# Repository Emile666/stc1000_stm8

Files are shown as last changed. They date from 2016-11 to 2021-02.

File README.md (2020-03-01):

STC-1000p-STM8
==========

This version of the STC-1000p (STC-1000p-STM8) is heavily based on the beautiful work from Mats Staffansson (https://github.com/matsstaff/stc1000p), where he creates an open-source implementation of firmware(s) for the STC-1000 dual stage thermostat.
Mats version is used by numerous home-brewers for automating their brewery / climate chamber. The hardware is controlled by a **PIC16F1828** microcontroller (µC), which is pretty limited. Despite these limitations Mats succeeded in
adding 6 profiles with up to 9 temperature-time pairs per profile.

I bought a couple of STC-1000 devices which had another µC with completely different hardware on-board. It is the **STM8S003F3** µC. Being the electrical engineer that I am, I wanted to reverse engineer
the hardware, create the schematics and new boards and (like Mats) add new features. You can find the schematics (with the Eagle design files) all here. I also used Mats software as a start, but needed to heavily modify it in order
to run on the new hardware platform.

The following additional features were added, which were not present in Mats' firmware (See the [user-manual](./usermanual/README.md) for more details):
- **PID-Control with SSR**: This firmware version has PID-control built-in and the output is available at the connector block for direct control of a Solid-State Relay (SSR). Just set the **Ts** parameter to a non-zero value to enable PID-control.
- **Refrigerator mode with compressor fan control**: If you connect a second temperature probe and set the **Pb2** parameter to 2, you can control a refrigerator and the compressor fan at the same time. The first temperature probe goes inside the refrigerator as usual, the second one is connected to one of the compressor output pipes. The cooling output controls the refrigerator itself, the heating output is now used for the compressor fan. I am using this to control a keg-cooler (replacing the stock controller for a STC1000).

So, for those of you who have this version of the STC-1000: enjoy! Because now you can have the same (and more) functionality as Mats realised in the PIC version of the STC-1000. There's only one real drawback: the STM8 µC
only has 128 bytes of EEPROM, so the number of profiles and the number of temperature-time pairs per profile needed to be reduced. But you get more features as a standard (switchable) option (instead of programming a different firmware version). 
For those of you willing to do some de-soldering (see text below): you can replace the µC with a **STM8S103F3** µC that has 640 bytes of EEPROM. Then you have the 6 profiles with all temperature-time pairs again.

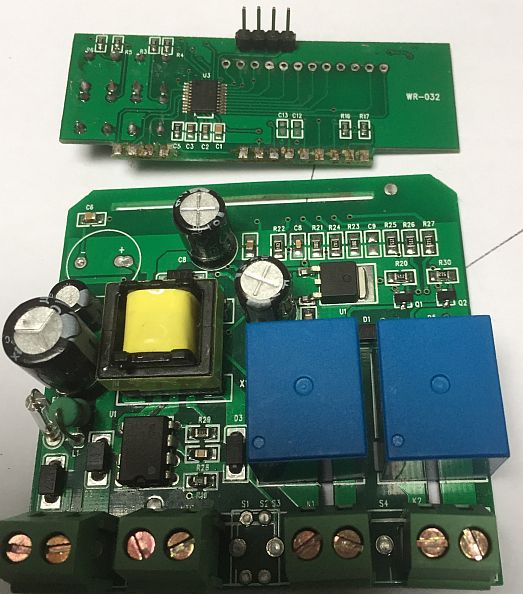
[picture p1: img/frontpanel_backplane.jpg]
STC-1000
<br>
*The frontpanel and backplane of the STC-1000 device*

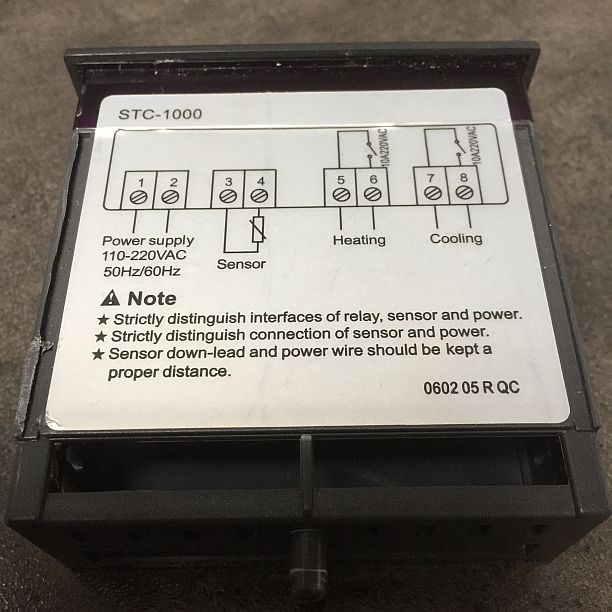
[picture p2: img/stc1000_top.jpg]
stc-1000-top
<br>
*The top of the STC-1000 device. Note the label '0602 05 R QC'*

If you happen to have an STC-1000 device without the label, you could have the newer hardware revision (**WR-032 v2**). It is almost the same, but has a few changes. Read more about this [here](./WR-032-v2-2016-4-7.md).

Questions?
----------
Please don't open github issues for general questions. Only open an issue if you discovered an actual bug or have a (realistic) feature request (or better yet, send a pull request).

Quick start
-----------
You'd need one of those fancy coloured ST-Link V2 USB adapter (which are very cheap to find on ebay) and of-course an STC-1000 with a STM8. Mine has a label '0602 05 R QC' on top, the Printed Circuit-Board (PCB) itself has a mark 'WR-032'.
 
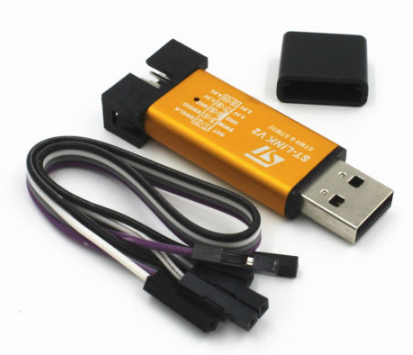
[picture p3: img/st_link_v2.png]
st-link-v2
<br>
*The ST-Link V2 USB adapter*

The frontpanel PCB already has a 4-pin connector (labeled with SIG, RST, VCC and GND). Solder some pins to this and connect the ST-Link adapter (use GND-GND, RST-RST and SWIM-SIG). Power up the STC-1000 device, so that it uses it's own
power-supply (in this way, the 4th VCC pin on the connecter is not needed). **Please be aware that most of the PCB is directly connected to the MAINS voltage, so keep your fingers out of it!**

This is all you need to reprogram the device! Now power-up the STC-1000 and connect the ST-Link V2 USB to it. 

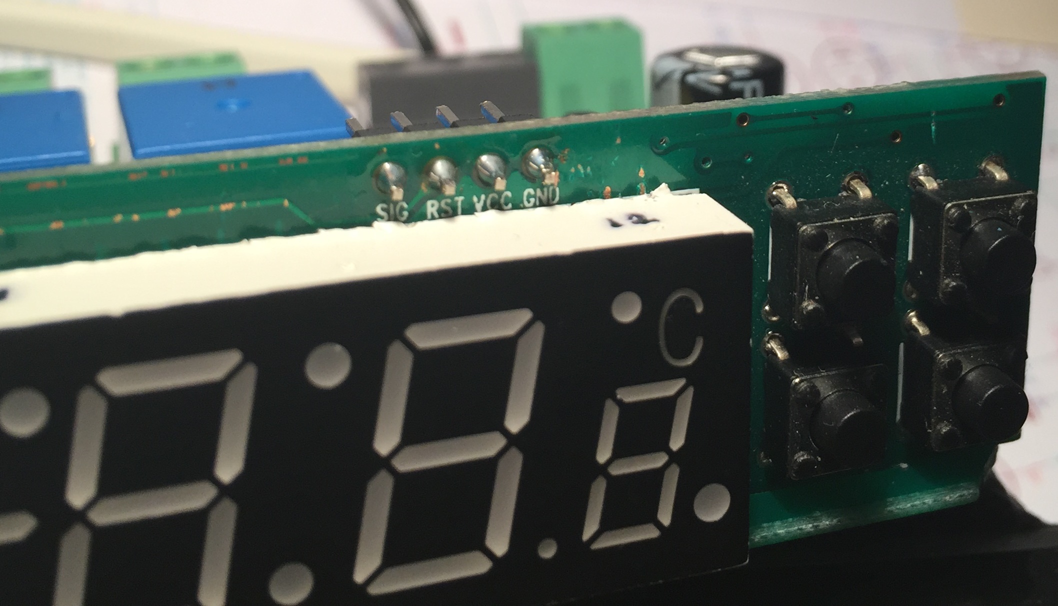
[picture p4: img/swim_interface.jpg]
swim-interface
<br>
*The Programming Interface. Note that you have to solder the 4-pins in place!*

Method 1: Just program it with ST Visual Programmer
-------------------------
This is the best method if you just want to flash the STC-1000 with the software provided and you don't want to change any software functionality.

- Download the ST Visual Programmer (STVP) software, unpack the .zip file and install it. This file can be downloaded free of charge from the ST website (st.com). Just search for 'STVP-STM8', the file to download is called en.stvp-stm8.zip.
- Run the STVP program, then click on Project -> Open..., select the **stvp_stm8s003f3_4pr_5tt.stp** file and open it. This file is located in src\Debug\Exe. You can safely ignore the 'address out of range' warnings, this is not a problem. Both the *Program Memory* tab and the *Data Memory* tabs are now filled with the data from the .hex file. Check that these tabs are indeed filled with data.
- Now find the button that says "Program all tabs" or click Program->All Tabs. This will program the microcontroller with the new functionality.

Note: there's also a project and .hex file for the **STM8S103F3** microcontroller (with 6 profiles and 9 temperature-time pairs). Use this version when you have replaced the stock microcontroller (see text below).

Method 2: Program and install complete development environment
-------------------------
This is the best method for anyone wanting to flash the STC-1000 and be able to make changes to the software.

- Download and install the IAR development environment for STM8 from the IAR website, which can be downloaded free of charge. Use the code-size limited version. After having installed this, the drivers for the ST-Link USB adapter are also installed.
- If you have downloaded the project- and source-files, open the workspace in IAR (File -> Open -> Workspace... -> stc1000p_dev.eww), then do a Project -> Rebuild All.
- The µC has Read-Only-Protection (ROP) enabled and this needs to be disabled before the new firmware can be uploaded. Click on ST-LINK -> Option Bytes... The following dialog box opens:
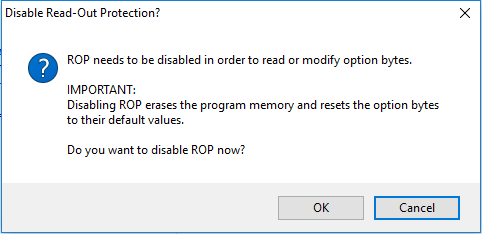
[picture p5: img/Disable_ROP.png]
rop-protection
<br>
*The Read-Only-Protection dialog box. Press OK to continue*
- If ROP protection is disabled (and your stock program has been erased, with no way of getting this back), press Ctrl-D. This opens the debugger and transfers the code to the microcontroller. 
- Press Ctrl-Shift-D to Stop Debugging. Remove the wires, re-cycle power and you are good to go!

Introduction (taken from https://github.com/matsstaff/stc1000p)
----------------------------------------------------------
The STC-1000 is a dual stage (that is, it can control heating *and* cooling) thermostat that is pretty affordable. It is microcontroller operated, that means there is a sort of 'computer on a chip' that reads the temperature of the probe, turns the relays on and off, reads the state of the buttons and updates the display. 
To do all this, the microcontroller needs to be programmed to perform these tasks. The program is stored in non volatile (flash) memory that is retained when there is no power. The microcontroller can be reprogrammed (flashed) with a new program (firmware), that can other or additional tasks. 
To do that, a new firmware is needed and you need a programmer that can send it to the microcontroller the way it expects it. The STC-1000\-STM8 project provides both these things (and a few additional things as well).

So far so good, *but* there is a catch. Probably due to the popularity of the STC-1000, there are a number of clones out there. These are functionally (from a user perspective) equivalent, but are not based on the same design. 
Specifically, they use other microcontrollers that while having similar specifications, use completely different architectures. 

This STC-1000+ version is *only* compatible with the **WR-032** version of the STC-1000 as this supports the **STM8S003F3** microcontroller, for which you have a code-size limited (8K) version of IAR available. IAR is the embedded development tool which you use to program the device in the C-language.
To upload (flash) the microcontroller, you also need the ST-Link V2 USB adapter ($2-$3 on ebay). There are official ST-Link programmers to purchase, but they typically cost a lot more. Neither of these options are very cost effective, considering the price of the STC-1000. 

Schematics
----------
I reversed engineered both the frontpanel PCB as well as the backplane PCB. The frontpanel PCB holds the buttons, the 7-segment display (3 digit common-cathode) as well as the **STM8S003F3** µC. There's an ingenious soldered connection that connects the frontpanel PCB to the backplane PCB. The backplane PCB holds both relays (able to switch 12A at 230VAC), the power-supply (12V and 5V) and the connectors. The schematics were made with the Eagle PCB program.

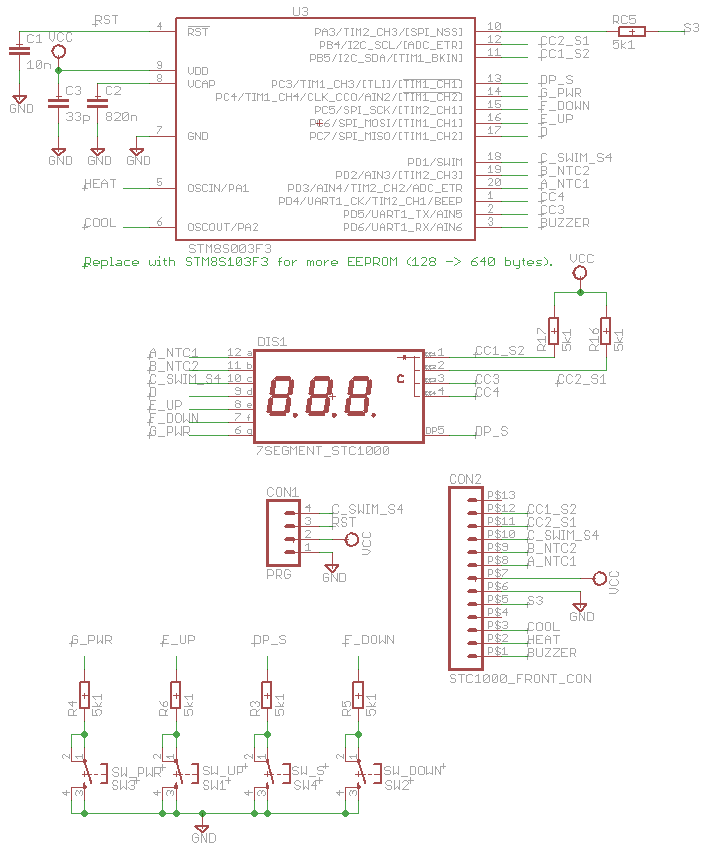
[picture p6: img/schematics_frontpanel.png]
frontpanel
<br>
*Eagle schematic of the Frontpanel PCB*

Two interesting features are shown in this schematic:
- The **S1** and **S2** lines. It looks likes this is an **I<sup>2</sup>C** interface. Interesting feature for those of you willing to do some more hacking! It is not used in this firmware version, these lines are solely for multiplexing the 7-segment displays.
- The **S3** line. Now this is interesting, it is the only hardware pin *NOT* used. The new firmware uses it to switch an SSR (with a slow PWM signal) controlled by a PID-controller. But I guess it can be used for other purposes as well.

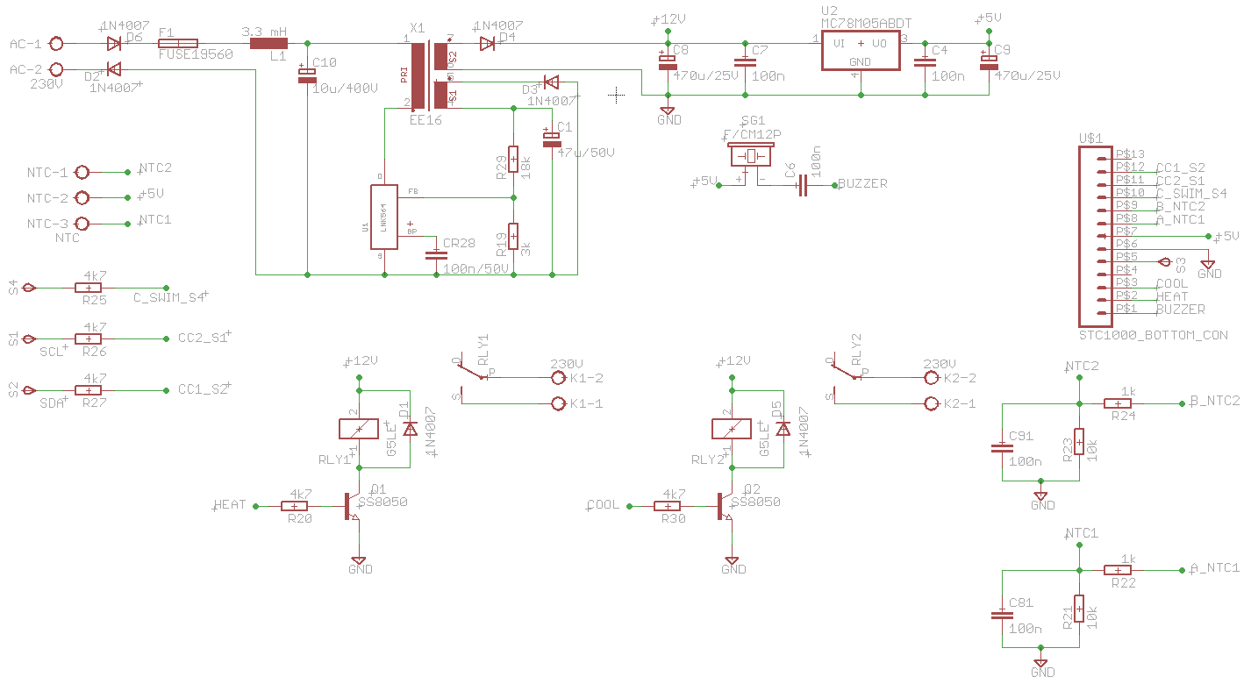
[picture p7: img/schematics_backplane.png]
backplane
<br>
*Eagle schematic of the Backplane PCB*

Replacing the STM8S003F3 µC for more EEPOM size
-----------------------------------------------
You do not need to do this, but if you replace the existing **STM8S003F3** microcontroller (µC) with a **STM8S103F3** µC, you get 640 bytes of EEPROM and you can have 6 profiles with up to 9 temperature-time pairs (same as in Mats his version).
You can skip this section if you are not into soldering small devices and the default profiles are oke for you. To replace the device, you would need the following:
- A new **STM8S103F3P6** device (Mouser part nr. 511-STM8S103F3P6). This is a 20-pin TSSOP package that costs about a $1.
- A hot-air rework station for SMD devices (I bought a 858D hot-air station that is very affordable on ebay)
- A soldering iron.
- Solder wick.
- Solder paste. This typically comes with an injection-needle for applying just a little paste on every solder pad.

To start with, we want to remove the frontpanel PCB from the backplane. Remove all the solder-joints with the solder wick. Place the solder wick over the solder-joints, heat it up with the soldering iron and make sure that the solder wick absorbs all solder.
After having done this, it is possible to remove the frontpanel from the backplane with just a little bit of pulling. Be careful, since you don't want to break anything.

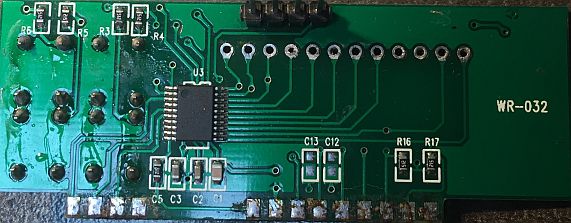
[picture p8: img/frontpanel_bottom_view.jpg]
frontpanel removed
<br>
*This is how it looks after the frontpanel is removed from the backplane*

Next: use the hot-air to heat-up the pins on one side of the µC. Use a sharp knife and place it under the µC. Carefully lift-up one side. Do not overheat, since you could damage the PCB tracks. If this is done, let it cool down and heat-up the other side. When the solder melts, it is easy to remove the µC. Use the solder-wick again to remove excess solder from the solder-pads.

If you don't have access to a hot-air rework station, here's a tip from Mats himself: one can can simply thread a thin wire under the legs on one side of the IC, fix one end of the wire and heat the legs with a soldering iron (starting at the other end) while keeping the wire under tension. As the solder melts, you pull the wire under the leg/pad, freeing them.

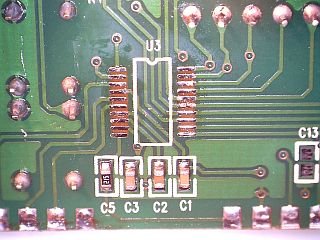
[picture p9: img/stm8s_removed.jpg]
uC removed
<br>
*This is how it looks after the microcontroller is removed*

Then: apply solder paste to the solder-pads of the µC and position the **STM8S103F3P6** µC exactly above the pads. Note the orientation of the device (there's a small circle denoting pin 1), you don't want to solder it upside-down! Position the µC exactly above the solder-pads, make sure the position is correct for all pins and use the hot-air station again to solder the new IC. Let is cool down again. It would be wise at this point to connect the ST-Link V2 USB device to the programming connector and see if you can connect to the device. If all is well, solder both PCB boards back together. If not, check all solder-joints to see if one or more pins are not connected properly.

Updates
-------

|Date|Release|Description|
|----|---|---|
|2016-12-02|v1.10|reduced code-size by removing unions and bit-fields. Added description how to flash firmware with STVP program. Description added for v2 hardware.|
|2016-10-27|v1.00|First release, copied from https://github.com/matsstaff/stc1000p |

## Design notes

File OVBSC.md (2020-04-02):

STC\-1000+ One vessel brew system controller, STM8 version
============================================
This is a firmware version for the STC-1000 dual stage thermostat with an STM8 microcontroller. The purpose is to serve as a simple semi-automatic controller for a one vessel brewing system (OVBSC).
Note: almost all information on this page is a direct copy from Mats' OVBSC page (https://github.com/matsstaff/stc1000p/tree/master/ovbsc). There are however a few modifications made in this firmware, the most important one
being that there are no constant output (cO) parameters anymore. This is replaced by a PID-controller that controls the output.

By using a separate output for a Solid-State-Relay (SSR), you can connect any type of heater, since an SSR can typically switch a large current.

Features
--------
* Fahrenheit and Celsius adjustable
* Cheap, simple, semi automated one vessel brewing control
* Controls a pump and an electric heater
* Separate heater output for PID-controlled Solid-State-Relay (SSR)
* Alarm when user interaction is required
* Possible to delay heating of strike water
* PID-control during entire brew for accurate temperature control
* Four run-modes: OFF, run-program, constant output and constant temperature
* TODO: Manual pump control (on/off toggle) by pressing Up key for 3 seconds
* TODO: Heater control (on/off toggle) by pressing Down key for 3 seconds
* 1-6 mash steps, 0-4 hop addition alarms
* Pause program at any time
* Button acceleration, for frustrationless programming by buttons

Parameters
----------
|Menu item|Description|Values|
|---|---|---|
|Sd|Strike delay|0-999 minutes|
|St|Strike water setpoint|-40.0 to 140°C or -40.0 to 250°F|
|Pt1|Mash step 1 setpoint|-40.0 to 140°C or -40.0 to 250°F|
|Pd1|Mash step 1 duration|0-999 minutes|
|Pt2|Mash step 2 setpoint|-40.0 to 140°C or -40.0 to 250°F|
|Pd2|Mash step 2 duration|0-999 minutes|
|Pt3|Mash step 3 setpoint|-40.0 to 140°C or -40.0 to 250°F|
|Pd3|Mash step 3 duration|0-999 minutes|
|Pt4|Mash step 4 setpoint|-40.0 to 140°C or -40.0 to 250°F|
|Pd4|Mash step 4 duration|0-999 minutes|
|Pt5|Mash step 4 setpoint|-40.0 to 140°C or -40.0 to 250°F|
|Pd5|Mash step 4 duration|0-999 minutes|
|Pt6|Mash step 4 setpoint|-40.0 to 140°C or -40.0 to 250°F|
|Pd6|Mash step 4 duration|0-999 minutes|
|Ht|Hot break temperature|-40.0 to 140°C or -40.0 to 250°F|
|Hd|Hot break duration|0-999 minutes|
|bt|Boil temperature|-40.0 to 140°C or -40.0 to 250°F|
|bd|Boil duration|0-999 minutes|
|hd1|Hop alarm 1|0-999 minutes|
|hd2|Hop alarm 2|0-999 minutes|
|hd3|Hop alarm 3|0-999 minutes|
|hd4|Hop alarm 4|0-999 minutes|
|cF|Celsius or Fahrenheit display|0 = Celsius, 1 = Fahrenheit|
|tc|Temperature correction|-5.0 to 5°C or -10.0 to 10.0°F|
|Hc|Kc parameter for PID-controller in %/°C|-9999 to 9999|
|Ti|Ti parameter for PID-controller in seconds|0 to 9999|
|Td|Td parameter for PID-controller in seconds|0 to 9999|
|Ts|Ts parameter for PID-controller in seconds|0 to 9999|
|APF|Alarm/Pause control flags|0 to 511|
|PF|Pump control flags|0 to 31|
|cO|Manual mode output when Run mode is OFF|-200 to 200%|
|cSP|Manual mode temperature setpoint when Run mode is OFF|-40.0 to 140°C or -40.0 to 250°F|
|cP|Manual mode pump when Run mode is OFF|0 (=off) or 1 (=on)|
|ASd|Safety shutdown timer|0-999 minutes|
|rUn|Run mode|OFF, Pr (run program), Ct (manual mode thermostat), Co (manual mode constant output)|

Note on APF parameter: APF is a parameter that holds flags to enable/disable the alarm/pause points during the program. By default all alarms/pause points are enabled, but this parameter allows the user to skip some/all of them if so desired. To make adjustments, the desired behaviour needs to be calculated.

|Value|Description|
|---|---|
|1|Strike temp reached/dough in alarm|
|2|Strike temp reached/dough in pause|
|4|Mash done/sparge/start boil up alarm|
|8|Mash done/sparge/start boil up pause|
|16|Hop addition 1 alarm|
|32|Hop addition 2 alarm|
|64|Hop addition 3 alarm|
|128|Hop addition 4 alarm|
|256|Boil done/start chill alarm|

Add up the values for the alarms/pause points desired, and set that value to the APF parameter. Say for example you'd like to mash in cold, and want the controller to skip the alarm and pause after strike temp is reached, and just continue with the mash profile (but still keep the other alarms/pause points). Then sum up all the alarms (511) and subtract 1 (strike temp reached alarm) and 2 (strike temp reached pause). The value (508) is what you'd want to enter in APF.

Note on PF parameter: The PF parameter holds flags to indicate pump status during different stages of the program. By default the pump is on during the mash.

|Value|Description|
|---|---|
|1|Pump during heating of strike water|
|2|Pump during ramping up to reach next mash steps|
|4|Pump during the mash steps|
|8|Pump during heating up to reach hot break|
|16|Pump during hot break|

Similar to the APF parameter. Add upp the values of the stages when the pump should be active and enter it into the PF parameter.

Hardware usage
--------------

Pretty simple really. The cool output relay is used to control a pump, the S3 output is used to connect a Solid-State-Relay (SSR) that connects to a heater. See the 'PID-output for connection to a Solid-State Relay (SSR)' 
section in the [user-manual](./usermanual/README.md) for details.

The output is specified as a percentage and is controlled with slow PWM (that is they are pulsed on/off). So for example, if the PID-output is 75%, the SSR switches 9.375 seconds ON and 2.625 seconds OFF (timebase for this slow PWM signal is 12 seconds).
Typically there's a LED on a SSR, so you can see when the SSR is on or off. Also, the heating LED on the display shows the SSR status. The PID-controller is active most of the time and only needs a setpoint temperature to control everything. 
This is also the case in 'constant temperature' mode where it uses the *cSP* setpoint temperature. Only in 'constant output' mode, the PID-controller is not used and the controller output is directly set to *cO* percent.

Program algorithm
-----------------

* Wait *Sd* minutes (with all outputs off)
* PID-controller on with setpoint *St*
* Wait until temp >= *St* (or end program if countdown-timer = 0)
* St alarm if APF flag set, countdown-timer = *ASd* minutes
* Wait until keypress (or end program if countdown-timer = 0)
* Pause if APF flag set (output off, pump off)
* (This is when you dough in and do manual vorlauf)
* Wait until power key is pressed
* *x* = 1
* *Init mashstep*: PID-controller uses setpoint *Ptx*, pump on if PF flag set, countdown = *ASd* minutes
* Wait until temp >= *Ptx* (or end program if countdown-timer = 0)
* countdown-timer = *Pdx*, pump on if PF flag set
* Wait until countdown-timer = 0
* x = x+1
* if x <= 6 goto *Init mashstep* 
* bU alarm if APF flag set, countdown-timer = *ASd* minutes
* Wait until keypress (or end program if countdown-timer = 0)
* Pause if APF flag set (output off, pump off)
* (This is when you remove grains and sparge)
* Wait until power key is pressed
* PID-controller uses setpoint *Ht*, pump on if PF flag set, countdown-timer = *ASd* minutes
* Wait until temp >= *Ht* (or end program if countdown-timer = 0)
* countdown-timer = *Hd* minutes, pump on if PF flag set
* Wait until countdown-timer = 0
* PID-controller uses setpoint *bt*, countdown-timer = *bd* minutes, pump off
* Wait until countdown-timer = 0, if countdown-timer = *hdx* then hdx alarm if APF flag set
* Ch alarm if APF flag set, output = 0, pump off, end program

During the program the keys have the following function:
- a single press on the power button will pause the program (during pause, a LED will flash and all outputs will be off). Press the power button again and the program will resume.
- a 3-second press on the Up key toggles the pump on/off (not implemented yet).
- a 3-second press on the Down key toggles the PID-controller on/off (not implemented yet).

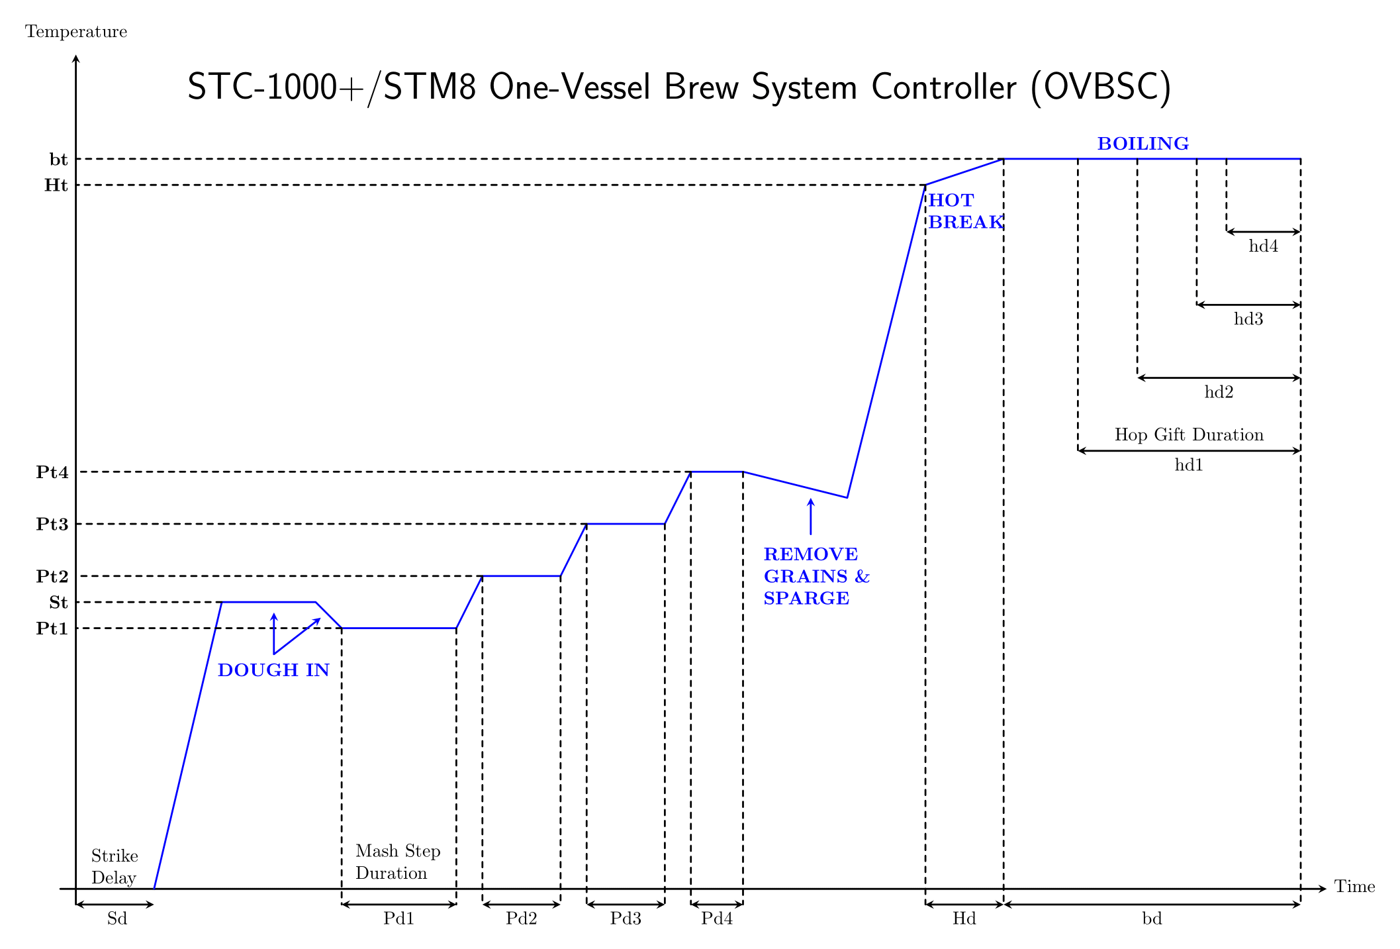
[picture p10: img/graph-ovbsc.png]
Graphical representation
<br>
*Fig4: Graphical representation of the algorithm*

Now, I will try as best I can, to explain the algorithm and key concepts in 'english'.<br>
The program starts off with a delay of *Sd* minutes (strike delay), during this time it will do nothing but wait. This can be useful if you want to delay the heating of strike water, so it will be warm by the time you need it 
(don't recommend leaving it unattended, do so at your own risk). *Sd* can of course be set to 0 to start immediately.<br>

Reaching strike temperature is done by the PID-controller that uses setpoint value *St*. If the PID-controller is properly tuned (*Hc*, *Ti*, *Td*, *Ts* parameters), it will quickly reach its setpoint-temperature with no overshoot.<br>

Once strike temperature is reached, the alarm will go off if the corresponding APF flag is set and 'St' will flash on the display. The PID-controller will continue to control the *St* setpoint temperature. 
If the alarm is not acknowledged within *ASd* (automatic shutdown delay) minutes, the program will be stopped. Once acknowledged (by pressing any button), the program will pause if the corresponding APF flag is set 
(all outputs off) and during this pause you dough in your grains. Press the *power* button to continue the program.<br>

In a similar way, for each of the mashing steps, the PID-controller will continue to control the temperature by using the proper setpoint-temperature (*Pt1* to *Pt6*). Once this setpoint-temperature is reached, it holds the mash
step temperature for the programmed duration.<br>

When mashing is done, the alarm will go off again (again if the corresponding APF flag is set) and 'bU' (boil up) is flashing on the display. The PID-controller will now use the *Ht* setpoint temperature. Acknowledge the alarm and the unit will pause (APF flag...) again. Remove the grains and optionally sparge manually. Press *power* button to resume. <br>

Once *Ht* (hotbreak temperature) is reached, the PID-controller holds this temperature for *Hd* (hotbreak duration) minutes. The purpose of this, is that as the wort reaches boiling temp, proteins clump together and a foam is formed on the surface. The added nucleation points as well as the insulating effect of the foam can easily contribute to boil over. The heat will shortly break down the proteins (hot break), that will settle to the bottom of the kettle. So, to avoid boil over the power is reduced during this period. As an educated guess, you might want to set *Ht* a degree or so shy of your normal boiling temperature and *Hd* should probably be around 15 minutes.<br>

When *Hd* has passed, normal boil starts and the PID-controller now uses the *bt* setpoint temperature. Setting this temperature to 102-105 °C assures that the PID-output is 100 % on all the time. The timer also starts counting down the boil duration *bd*. When the timer matches a hop addition the alarm will sound and *hdx* will flash on the display. Acknowledge the alarm by pressing any button (and add the hops of course). Note that the *hdx* settings are in standard hop addition times as used in most recipies, that is the boil duration counted back from boil end.<br>

Once the boil is complete, output is turned off and the alarm goes off (flashing 'Ch' for chill). Acknowledge and chill your wort.<p>

An important note on *ASd*. This is in my opinion an important feature. Many of the steps in the program are timed. For example mash durations, boil duration and so on. But not every step is, for example, when 'stepping up' the temperature, the program will continue to heat until the temperature is reached, or during an alarm (except hop additions, during which the boil duration timer is running) when user input is required, during these times the timer is loaded with *ASd* instead and if not the condition is met within this timeframe, the program stops. This is of course for safety. *ASd* should therefore be set to the maximum of these duration + some wiggle room. For example, if it takes you around 35 minutes to reach strike temp and this is the longest of these delays, maybe set *ASd* to 45 minutes.<br>

Also, a note on switching times. The SSR is controlled with a fixed switching period (12.5 seconds). This is slow enough to control any large heating element (I connected a 3 kW heating element without any problem at all).

Updates
-------

|Date|Release|Description|
|----|---|---|
|2020-04-01|v1.00|First release, copied from Matsstaf and modified|

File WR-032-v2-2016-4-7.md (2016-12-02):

# New hardware revision WR-032 v2
==========

Recently (november 2016) I bought a couple of new STC-1000 devices and was amazed that, instead of the familiar WR-032 label, a new hardware revision was shipped. It was labeled **WR-032 v2** with date **2016/4/7**.

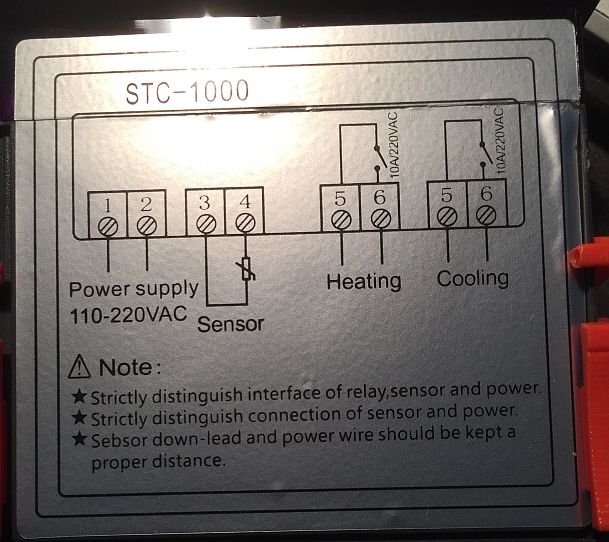
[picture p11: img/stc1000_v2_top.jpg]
stc-1000-top
<br>
*The top of the new STC-1000 device. Note that there's no label anymore!*

The frontpanel does state **WR-032 v2** but it seems that this is still the same as the original version. The microcontroller is still the **STM8S003F3** device, so no changes here. Only the backplane shows some changes.

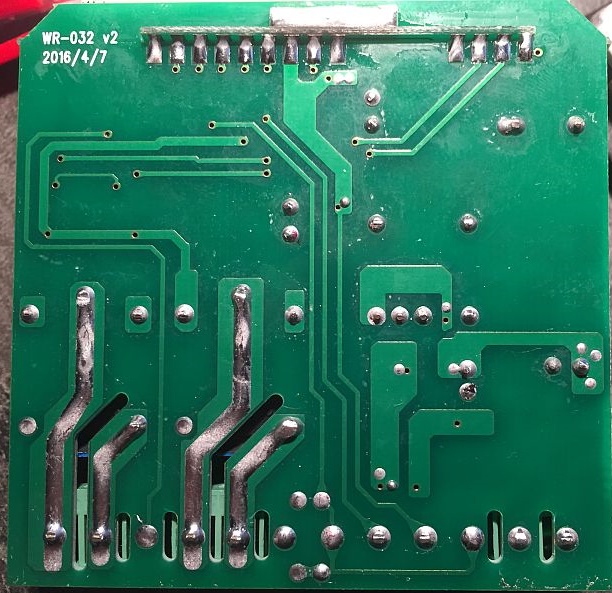
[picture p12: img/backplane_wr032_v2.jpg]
<br>
*The backplane of the STC-1000 device with the new hardware revision*

## What has changed from the first WR-032 revision?
----------
To start with, the new hardware revision is definitely NOT an improvement. No new features are added. The following things have changed:
- The DC-DC converter chip (LNK567) has been replaced by another IC. This is not something to worry about: there's still 12VDC and 5VDC being made
- The **S3 output** line is no longer wired to the terminal-blocks.
- The 2nd temperature probe is now also wired to the terminal-block pin (pin 4) that we used as GND. This needs to be fixed if we still want PID-controlled SSR output.
- Capacitor C9 is now populated (temperature conversion for 2nd temperature probe). This has no impact on the STC-1000p-STM8 firmware, since the ADC-input routine already deals with this.
- Resistors R25 (S4 output), R26 (S1 output) and R27 (S2 output) are no longer populated. This is also not a problem.

## What do we need to change?
-----------
- The GND connection at the 5-pin terminal-block needs to be connected to GND again. It is now connected to the second temperature probe.
- The **S3 output** needs to be connected to the SSR connection at the 5-pin terminal-block. This pin is now NOT connected.

## What if I don't want to change anything?
----------------------------------------------------------
- You loose the slow-PWM PID-controlled SSR output.
- A 5-pin terminal-block is no longer useful, since pin 4 is now connected to pin 1 (2nd temperature probe) and pin 5 is not connected. Solder a 3-pin terminal block in place, so you can still connect a 2nd temperature probe.

All other functionality will remain intact. So you can still have 2 temperature probes. Up to you to decide if you need to make the hardware changes.

## Ok, what do I need to change?
----------
To get the same functionality as with the original WR-032 hardware (in combination with the STC-1000p-STM8 firmware of-course), you need to prepare the connectors the same way you did with the original version:
- Remove the 2-pin terminal-block for the temperature sensor.
- Replace it with a 5-pin terminal-block with a pitch of 5 mm.

Then, proceed with the following:
- Cut the 2 wires going to and from pin-4 of the 5-pin terminal block. Cut where the **red** lines are in the picture. This pin is now completely isolated from anything else. Measure with a multimeter!
- Solder a wire between pin 1 of the 5-pin terminal block to the S1 solder-pad. This is the **yellow** line in the picture. Now the 2nd temperature probe is connected again with the original line.
- Solder the now isolated pin-4 of the 5-pin terminal block to the GND connection of the 470 µF/25V capacitor. This is the **black** line in the picture.
- Solder pin 5 of the 5-pin terminal-block to pin 5 of the frontpanel connector. This is the **S3-output** line and the **blue** line in the picture.

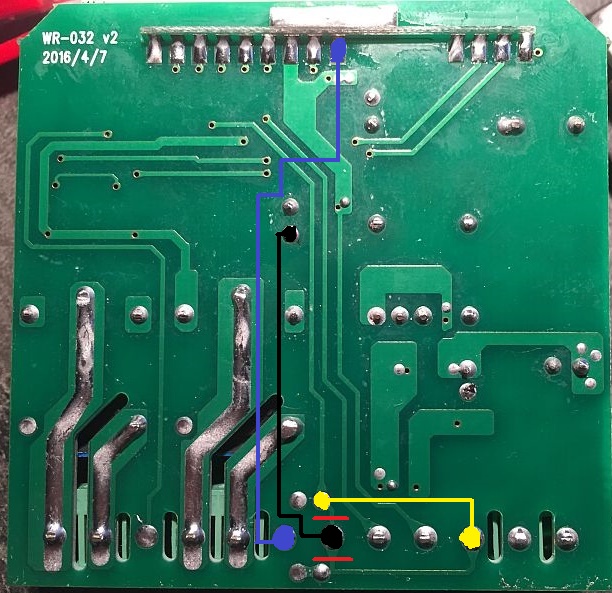
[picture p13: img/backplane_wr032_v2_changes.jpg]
<br>
*The backplane of the STC-1000 device with the proposed changes*

Now you have the same functionality again as with the standard WR-032 hardware revision.

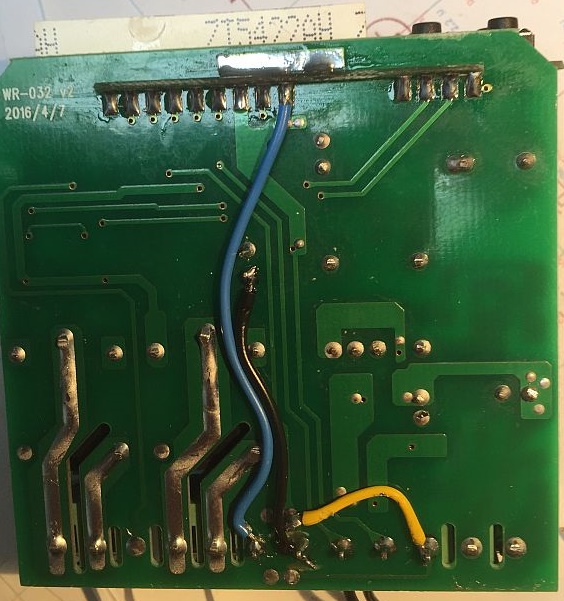
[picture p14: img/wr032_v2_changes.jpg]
wr032-v2-changes
<br>
*This is how it looks when the changes have been made*

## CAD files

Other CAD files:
src/Debug/Exe/stvp_stm8s103f3_6pr_9tt.stp
src/Debug/Exe/stvp_stm8s003f3_4pr_5tt.stp

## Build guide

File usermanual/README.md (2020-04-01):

STC-1000p-STM8 USER MANUAL<br>
=====================

Mats Staffansson / Emile

© 2014-2020

# Changelog

2016-11-04:	First version of STC-1000p for STM8<br>
2016-12-05: Direct- (heating-loop) or reverse-acting (cooling-loop) PID now selectable with **Hc** parameter<br>
2020-02-29: Option added (**Pb** = 2) to control a refrigerator and the compressor fan

# Features

* Fahrenheit or Celsius display selectable with **CF** parameter
* Minutes or hours time-base selectable with **Hrs** parameter
* PID-controller selectable with adjustable **Kc**, **Ti**, **Td** and **Ts** parameters
* PID-output polarity selectable with **Kc** parameter. Forward-acting (heating-loop) or reverse-acting (cooling-loop)
* PID-output signal (slow PWM, T=12.5 sec) present at **S3 output** for connection to a Solid-State Relay (SSR)
* Standard thermostat functionality available when PID-controller is disabled (**TS** parameter set to 0)
* Second temperature probe functionality selectable with **Pb2** parameter. If **Pb2** is set to 0, no second temperature probe is connected.
 ..+ With **Pb2** set to 1, the second temperature probe should measure the outside temperature. Used in thermostat control.
 ..+ With **Pb** set to 2, the second temperature probe should measure the compressor temperature of a refrigerator. Used in refrigerator mode to also control the compressor fan.
* Up to 4 profiles with up to 6 setpoints (6 profiles with 10 setpoints if the STM8S003F3 is replaced with a STM8S103FS µC)
* Each setpoint can be held for 1-999 hours (i.e. up to ~41 days) or 1-999 minutes (i.e. up to ~16 hours)
* Approximative ramping
* Somewhat intuitive menus for configuring
* Separate delay settings for cooling and heating
* Configurable hysteresis (allowable temp swing) from 0.0 to 2.5°C or 0.0 to 5.0°F
* User definable alarm when temperature is out of or within range
* Easy displaying of setpoint, thermostat/PID-mode, actual temperature (default), 2nd temperature and PID-output (%)

# Using the STC-1000p-STM8 firmware

## Navigation and menus

By default the current temperature is displayed in °C or °F on the display, depending on the **CF** parameter. Pressing the 'S' button enters the menu. Pressing button 'Up' and 'Down' scrolls through the menu items. 
Button 'S' selects and 'Power' button steps back or cancels current selection.

The menu is divided in two steps. When first pressing 'S', the following choices are presented:

|Menu item|Description|
|---|---|
|Pr0|Set parameters for profile 0|
|Pr1|Set parameters for profile 1|
|Pr2|Set parameters for profile 2|
|Pr3|Set parameters for profile 3|
|Pr4|Set parameters for profile 4 (STM8S103F3 only)|
|Pr5|Set parameters for profile 5 (STM8S103F3 only)|
|Set|Settings menu|
*Table 2: Menu items*

Selecting one of the profiles enters the submenu for that profile.

Pr0-3 submenus have the following items:

|Sub menu item|Description|Values|
|---|---|---|
|SP0|Set setpoint 0|-40.0 to 140͒°C or -40.0 to 250°F|
|dh0|Set duration 0|0 to 999 hours|
|...|Set setpoint/duration x|...|
|dh4 (dh8 with STM8S103F3)|Set duration 4 (8)|0 to 999 hours|
|SP5 (SP9 with STM8S103FS)|Set setpoint 5 (9)|-40.0 to 140°C or -40.0 to 250°F|
*Table 3: Profile sub-menu items*

You can change all the setpoints and durations associated with that profile from here. When running the programmed profile, *SP0* will be the initial setpoint, it will be held for *dh0* hours (unless ramping is used). 
After that *SP1* will be used as setpoint for dh1 hours. The profile will stop running when a duration (*dh*) of 0 hours OR last step is reached (consider *dh5* implicitly 0). When the profile has ended, STC-1000p-STM8 will automatically switch to thermostat mode with the last reached setpoint. (So I guess you could also consider a *dh* value of 0 as infinite hours).

The settings menu has the following items:

|Sub menu item|Description|Values|
|---|---|---|
|SP|Set setpoint|-40 to 140°C or -40 to 250°F|
|hy|Set hysteresis|0.0 to 5.0°C or 0.0 to 10.0°F|
|hy2|Set hysteresis for 2nd temp probe|0.0 to 25.0°C or 0.0 to 50.0°F|
|tc|Set temperature correction|-5.0 to 5.0°C or -10.0 to 10.0°F|
|tc2|Set temperature correction for 2nd temp probe|-5.0 to 5.0°C or -10.0 to 10.0°F|
|SA|Setpoint alarm|0 = off, -40 to 40°C or -80 to 80°F|
|St|Set current profile step|0 to 4 (8)|
|dh|Set current profile duration|0 to 999 hours|
|cd|Set cooling delay|0 to 60 minutes|
|hd|Set heating delay|0 to 60 minutes|
|rP|Ramping|0 = off, 1 = on|
|cF|Celsius or Fahrenheit display|0 = Celsius, 1 = Fahrenheit|
|Pb2|Enable second temp probe for use in thermostat control|0 = off, 1 = on, 2 = refrigerator mode with compressor fan control|
|HrS|Select Hours or Minutes time-base|0 = minutes, 1 = hours|
|Hc|Kc parameter for PID-controller in %/°C|-9999 to 9999|
|Ti|Ti parameter for PID-controller in seconds|0 to 9999|
|Td|Td parameter for PID-controller in seconds|0 to 9999|
|Ts|Ts parameter for PID-controller in seconds|0 to 9999|
|rn|Set run mode|Pr0 to Pr5 and th|
*Table 4: Settings sub-menu items*

**Setpoint**, well... The desired temperature to keep. The way STC-1000p-STM8 firmware works, setpoint is *always* the value the thermostat or the PID-controller strives towards, even when running a profile. What the profile does is simply setting the setpoint at given times.

**Hysteresis**: This parameter is used when the thermostat controls the temperature (**Ts** is set to 0). This parameter then controls the allowable temperature range around the setpoint where the thermostat will not change state. For example, if temperature is greater than setpoint + hysteresis AND the time passed since last cooling cycle is greater than cooling delay, then cooling relay will be engaged. Once the temperature reaches setpoint again, cooling relay will be disengaged.

**Hysteresis 2**, This parameter is used when the thermostat controls the temperature (**Ts** is set to 0). Futhermore if **Pb2** is set to 1, temperature probe 2 should measure the environmental temperature. Now the allowable temperature range around the setpoint for temperature probe 2 is controlled. For example, if temperature 2 is less than **SP - hy2**, the cooling relay will cut out even if **SP - hy** has not been reached for temperature. Also, cooling will not be allowed again, until temperature 2 exceeds **SP - 0.5 \* hy2** (that is, it has regained at least half the hysteresis).<br>
If **Pb2** is set to 2, then this parameter controls the compressor fan (which should be connected to the heater output). For example: if **Hysteresis 2** is set to 100 E-1 °C, the compressor fan is switched on when probe 2 temperature exceeds 35 °C (30 + **Hysteresis 2**/2) and switched off when probe 2 temperature is below 25 °C (30 - **Hysteresis 2**/2). Temperature probe 2 should in this case be attached to one of the compressor output pipes (which should get hot when the compressor is turned on).

**Temperature correction**, will be added to the temperature sensor, this allows the user to calibrate the temperature reading. It is best to calibrate with a precision resistor of 10 k Ohms (1% tolerance). Replace the temperature sensor with such a resistor, let the STC-1000p-STM8 run for at-least half an hour and adjust this parameter such that the temperature display is set to 25.0 °C.

**Temperature correction 2**, same as *temperature correction*, but for the second temperature probe. If you remove the existing 2-pin terminal-block and replace it with a 5-pin terminal-block (see below for details), you can connect a second temperature sensor. The 1st temperature sensor is connected to pins 2 and 3 (seen from the left), the 2nd temperature sensor can now be connected between 1 and 2. Enable this 2nd sensor with the **Pb2** parameter.

**Setpoint alarm**, if setpoint alarm is greater than 0.0, then the alarm will sound once temperature differs from *SP* by more than *SA* degrees (this can be useful to warn against malfunctions, such as fridge door not closed or probe not attached to carboy). If *SA* is less than 0.0, then the alarm will sound if the temperature does **NOT** differ by more than (-) *SA* degrees (this could be used as an indication that wort has finally reached pitching temp). If *SA* is set to 0.0, the alarm will be disabled. If the alarm is tripped, then the buzzer will sound and the display will flash between temperature display and showing "SA", it will not however disengage the outputs and the unit will continue to work as normal. Please note, that care needs to be taken when running a profile (especially when not using ramping or with steep ramps) to allow for a sufficiently large margin, or the alarm could be tripped when setpoint changes.

**Current profile step** and **current profile duration**, allows 'jumping' in the profile. Step and duration are updated automatically when running the profile, but can also be set manually at any time. Note that profile step and profile duration are the variables directly used to keep track of progress in a profile. Little or no validation is made of what values are entered. It is up to the user to know what he/she is doing by changing these values. Changing these values will not take effect until next point in profile is calculated, which could be as much as one hour. Every hour, current duration, *dh* (and if next step is reached, also current step, *St*) is updated with new value(s). That means in case of a power outage, STC-1000p-STM8 will pick up (to within the hour) from where it left off. Current profile step and current profile duration are only available in the menu when a profile is currently running.

**Cooling** and **heating delay** is the minimum 'off time' for each relay, to spare the compressor and relays from short cycling. If the the temperature is too high or too low, but the delay has not yet been met, the corresponding LED (heating/cooling) will blink, indicating that the controller is waiting to for the delay to pass before it will start heating or cooling. When the controller is powered on, the initial delay (for both heating and cooling) will **always** be approximately 1 minute, regardless of the settings. That is because even if your system could tolerate no heating or cooling delays during normal control (i.e. *cd* and/or *hd* set to zero), it would be undesirable for the relay to rapidly turn on and off in the event of a power outage causing mains power to fluctuate. Both cooling and heating delays are loaded when either cooling/heating relays switched off. So, for instance if you set cooling delay to 60 minutes and setpoint is reached, turning cooling relay off, it will be approximately one hour until cooling relay will be allowed to switch on again, even if you change your mind and change the setting in EEPROM (i.e. it will not affect the current cycle).

The delay can be used to prevent oscillation (hunting). For example, setting an appropriately long heating delay can prevent the heater coming on if the cooling cycle causes an undershoot that would otherwise cause heater to run. What is 'appropriate' depends on your setup.

**Ramping** can be used to gradually increase the setpoint when going from one setpoint to another. See below for a more detailed explanation.

**Celsius or Fahrenheit** can be used to set display mode for temperatures to Celsius or Fahrenheit. Note that the values stored in EEPROM are not directly changed with it, so if you change this, you need to make sure that the stored parameters are updated!

**Second temperature probe** can be used to enable the second temperature probe. See below for a more detailed explanation.

**Hours or Minutes** can be used to select between a time-mode in hours or minutes. Typically the minutes time-mode is selected when you want to control a brewing-session. When controlling a fermentation in a climate controlled chamber, you typically select hours.

**Hc**, this is the proportional gain for the PID controller. It also selects the PID-mode: **forward-acting** (**Hc** > 0) or **reverse-acting** (**Hc** < 0). See below for a more detailed explanation.

**Ti**, this is the integral time-constant in seconds for the PID controller. See below for a more detailed explanation.

**Td**, this is the differential time-constant in seconds for the PID controller. See below for a more detailed explanation.

**Ts**, this is the sample-time in seconds for the PID controller. The PID-controller runs every **Ts** seconds. When set to 0, the PID-controller is disabled and normal thermostat (on-off) control is enabled. If you set this time too small, the pid-controller becomes too sensitive for changes in temperature. A decent value for temperature control is around 20-30 seconds (yes, that slow! It's temperature remember, doesn't change that quick). See below for a more detailed explanation.

**Run mode**, selecting *Pr0* to *Pr3* (*Pr5* with an STM8S103F3) will start the corresponding profile running from step 0, duration 0. Selecting *th* (when **Ts** = 0) or *PId* (when **Ts** > 0) will switch to thermostat/PID mode, the last setpoint from the previously running profile will be retained as the current setpoint when switching from a profile to thermostat/PID mode.

## Thermostat mode (**Ts** = 0)

When mode is set to thermostat (the **Ts** parameter needs to be set to 0), setpoint, *SP*, will not change and the controller will aim to keep the temperature to within the range of *SP* ± *hy*. Much like how the normal STC-1000 firmware works. The thermostat control runs once every second. The PID-controller output with the **S3 output** (for connection to a SSR) is disabled in this case.

## PID-Control mode (**Ts** > 0)

When the **Ts** parameter is set to a value > 0, the PID-controller is enabled and thermostat-control is disabled. Both the heating and the cooling relays are switched off in this mode. The PID-controller uses a sophisticated algorithm (a Takahashi Type C velocity algorithm) where the new output value is based upon the previous output value. The derivation of the algorithm for this controller is given in the .pdf document [PID Controller Calculus](./PID_Controller_Calculus.pdf).
The PID-controller is controlled with the *proportional gain*, *integral time-constant*, *differential time-constant* and the *Sample-Time*. They all work closely together. For more information on how to select optimum settings for a PID-controller, please refer to http://www.vandelogt.nl/uk_regelen_pid.php

The pid-output is a percentage between 0.0 and +100.0 %. It is in E-1 %, so a value of 123 actually means 12.3 %. This value can be seen by pressing the PWR button twice (one press shows the 2nd temperature, the 2nd press shows the pid-output percentage). This is where the polarity of the **Hc** parameter comes into play. Set **Hc** to a positive value for a so-called **direct-acting** process loop. This means that when the PID-output increases, the temperature (which is the process variable, or PV) also eventually increases. Of course, a true process is usually a complex transfer function that includes time delays. Here, we are only interested in the direction of change of the process variable in response to a PID-output change. Most process loops will be **direct-acting**, such as a temperature loop. An increase in the heat applied increases the temperature. Accordingly, direct-acting loops are sometimes called heating loops.

Direct-Acting<br>
*A Direct-Acting process control loop*

If the **Hc** parameter is set to a negative value, a so-called **reverse-acting** process loop is selected. A **reverse-acting** loop is one in which the process has a negative gain, as shown below. An increase in the control output results in a decrease in temperature. This is commonly found in refrigeration controls, where an increase in the cooling input causes a decrease in the process variable (the temperature). Accordingly, reverse-acting loops are sometimes called cooling loops.

Reverse-Acting<br>
*A Reverse-Acting process control loop*

**Source:** the above text and both images are copied from (and slightly adapted) from the DL05 Micro PLC User Manual, which has an excellent chapter (chapter 8) on PID-control.

The pid-output percentage is available at the **S3 output** as a slow PWM signal (period-time is 12.5 seconds), with the duty-cycle corresponding with the PID-output percentage.
For example: if the pid-output is equal to 200 (20.0 %), the **S3 output** is low (0 V) for 2.5 seconds and high (+5 V) for 10 seconds. This repeats continuously until another pid-output percentage is calculated. The Heating LED (when **Hc** is > 0) or the Cooling LED (when **Hc** is < 0) blinks at the same rate, so you can always see if the SSR is switched on.

## Running profiles

By entering the 'rn' submenu under settings and selecting a profile, the current duration, *dh*, and current step, *St*, is reset to zero and the initial setpoint for that profile, *SP0*, is loaded into *SP*. Even when running a profile, *SP* will always be the value the controller aims to keep. The profile simple updates *SP* during its course. When a profile is running the 'Set' LED on the display will be lit as an indication.

From the instant the profile is started a timer will be running, and every time that timer indicates that one hour has passed, current duration, *dh*, will be incremented. If and only if, it has reached the current step duration, *dhx*, current duration will be reset to zero and the current step, *St*, will be incremented and the next setpoint in the profile will be loaded into *SP*.  Note that all this only happens on one hour marks after the profile is started.

So, what will happen if the profile data is updated while the profile is running? Well, if that point has not been reached the data will be used. For example profile is running step 3 (with the first step being step 0). Then *SP3* has already been loaded into *SP*, so changing *SP0* - *SP3* will not have any effect on the current run. However, the duration *dh3* is still being evaluated every hour against the current duration, so changing it will have effect. 

Changing the current duration, *dh*, and current step, *St*, will also have effect, but the change will not be immediate, only on the next one hour mark will these new values be used in the calculation. You will need to know what you are doing when changing these values manually, but correctly used, it could come in handy.

Changing the setpoint, *SP*, when running a profile, will have immediate effect (as it is used by thermostat control), but it will be overwritten by profile when it reaches a new step.

Once the profile reaches the final setpoint, *SP5*, or a duration of zero hours, it will switch over to thermostat mode and maintain the last known setpoint indefinitely.

Finally, to stop a running profile, simply switch to thermostat mode.

## Ramping

The essence of ramping is to interpolate between the setpoints in a profile. This allows temperature changes to occur gradually instead of in steps.

Unfortunately, due to hardware limitations, true ramping (or true interpolation), is not feasible. So instead, an approximative approach is used.

Each step is divided into (at most) 64 substeps and on each substep, setpoint is updated by linear interpolation. The substeps only occur on one hour marks, so if the duration of the step is less than 64 hours, not all substeps will be used, if the duration is greater than 64 hours, setpoint will not be updated on every one hour mark, for example if duration is 192 hours (that is 8 days), setpoint will be updated every third hour).

Note, that in order to keep a constant temperature with ramping enabled, an extra setpoint with the same value will be needed (STC-1000p-STM8 will attempt to ramp between all setpoints, but if the setpoints are the same, then the setpoint will remain constant during the step).

You can think of the ramping as being true, even if this approximation is being used, the only caveat is, if you need a long ramp (over several days or weeks) and require it to be smoother. Then you may need to split it over several steps.

Another tip would be to try to design your profiles with ramping in mind, if possible (that is include the extra setpoints when keeping constant temperature is desired), even if you will not use ramping. That way, the profiles will work as expected even if ramping is enabled.

## Secondary temperature probe input

The STC-1000 (WR-032) hardware seems to have been designed to allow for two temperature probes to be connected, but the stock firmware only uses one and it alo only ships with one sensor. Also the screw type terminal for the second sensor is not populated as well as the noise reduction capacitor.

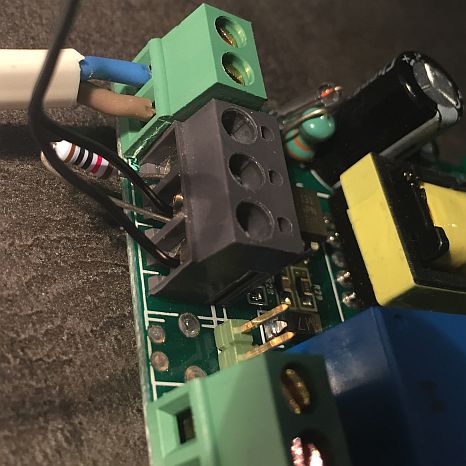
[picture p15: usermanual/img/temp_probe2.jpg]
Temperature probe header
<br>
*The temperature probe connections*

Here, you can see that there is room on the PCB for a three or even a five pole terminal-block. I find that the best way is to desolder the two pole terminal-block and solder back a five pole terminal-block. The picture shows a connected temperature sensor and a resistor to simulate the 2nd temperature probe. If you need an additional probe, what you are looking for is a 10k NTC probe with a beta value of 3435 (I'm guessing that is between 25-85 °C, but the retailers rarely specify). 

## Using secondary temperature probe input

The idea is to use the secondary temperature probe to measure the fridge air temperature or the temperature of a smaller thermal mass (water or sand) in the fridge. This should respond faster to the temperature fluctuations than the beer. By carefully limiting how far this temperature is allowed to deviate from the setpoint, it should be possible to limit the over/under-shoot that can occur as the heater/cooler continues to operate until the beer has reached the setpoint.<br>
The correct value for **hy2** will be dependent of the specific setup (and also the *hy* value) and will need to be set by trial and error or by analyzing how much over/under-shoot is seen and how far off setpoint the fridge temperature will go. This is a double edged sword, you do not want to set too tight hysteresis for the second temp probe as it will put more stress on the compressor and may make it harder to reach setpoint. But you also want to constrain it enough to be effective. Err on the safe side to begin with (using a larger **hy2** setting) and constrain it more as needed.

It should also be noted, that it would be a very good idea to make sure the two temperature probes are calibrated (at least in respect to each other) around the setpoint. See table 4

To enable use of the second temp probe in the thermostat logic (i.e. to enable **hy2** limits on temperature2), set **Pb2** to 1. Even with with it disabled it is still possible to switch to display the second temperature input using a short press on the power button. 

When you set **Pb2** to 2, the heating output is now used to control the compressor fan of the refrigerator. This is convenient if you want to control a refrigerator and you only want the compressor fan on when it is needed. Connect the second temperature probe in this case to one of the compressor output pipes (which should get hot when the compressor is on).

## PID-output for connection to a Solid-State Relay (SSR)

The PID-output signal is available at the rear of the STC-1000p-STM8, but it is not populated yet. Best thing to do is to remove the existing temperature probe connector and re-solder a 5-pin terminal block with a pitch of 5 mm (Mouser part nr. 523-ELM051200). In the picture below I improvised with a 3-pin and 2-pin terminal block (I didn't have a 5-pin block yet). 
Now it is possible to connect a 2nd temperature probe AND an SSR to this.

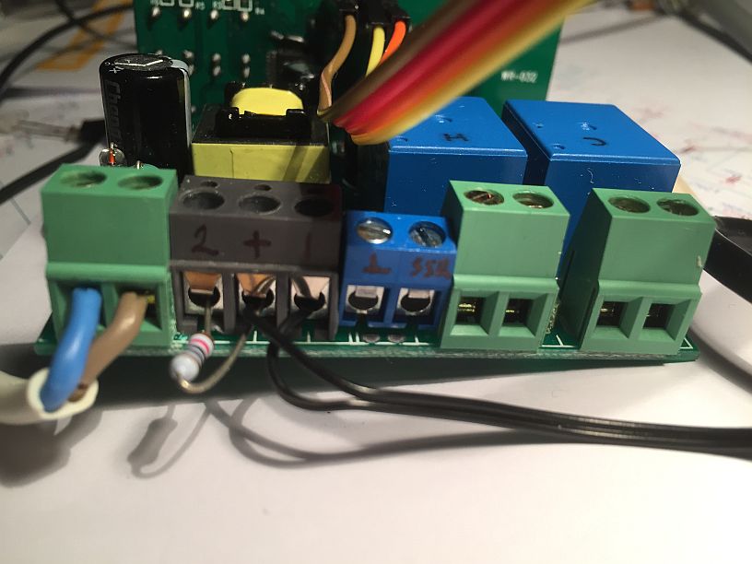
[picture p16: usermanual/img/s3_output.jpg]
S3 output
<br>
*The S3 output port (From left to right: 2nd temp probe, +5V, 1st temp probe, GND, to SSR)*

Although the microcontroller has sufficient capability to drive an SSR directly, there's a resistor mounted in series with the output pin. It is labeled as C5, but it clearly is a resistor with a value of 5.1 kOhms. This is too high to drive an SSR directly, so it has to removed and replaced by a short-cirtcuit or a zero Ohm resistor.

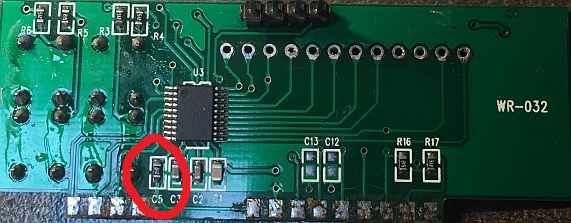
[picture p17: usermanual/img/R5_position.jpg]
Position of R5
<br>
*Position where R5 is to be found*

So do the following:
- Remove the resistor labeled as C5 with a soldering iron.
- Connect the two remaining solder-pins with a small wire or solder a zero (0) Ohm resistor in place.

Now connect a SSR to the terminal block at the back of the STC-1000. I tested with a Fortek SSR-40 DA and measured that it draws 9 mA when connected directly to +5V. So this is within the capability of the STM8 microcontroller.
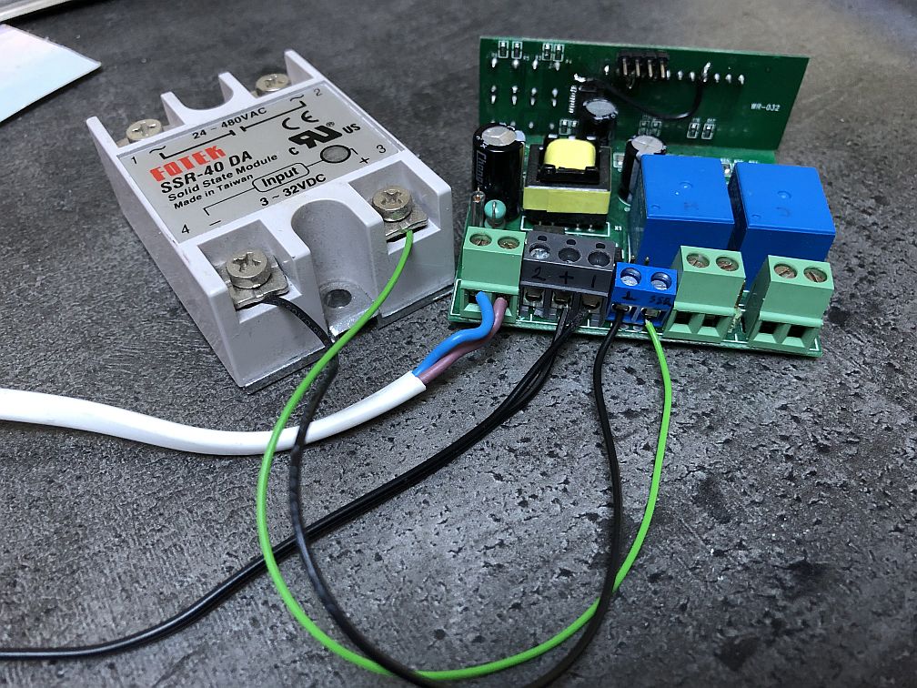
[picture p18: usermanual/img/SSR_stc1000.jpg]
SSR connected to STC-1000p
<br>
*How to connect an SSR to the STC-1000p*
 
## Additional features

**Sensor alarm**, if the measured temperature is out of range (indicating the sensor is not connected properly or broken), the internal buzzer will sound and display will show 'AL'. If secondary probe is enabled for thermostat control (**Pb2** = 1), then alarm will go off if that temperature goes out of range as well. On alarm, both relays will be disengaged and the heating and cooling delay will be reset to 1 minute. So, once the temperature in in range again (i.e. sensor is reconnected), temperature readings can stabilize before thermostat control takes over.

**Power off**, pressing and holding power button for a few seconds when the controller is not in menu (showing current temperature), will disable the relays (soft power off) and show 'OFF' on the display. To really power off, you need to cut mains power to the device. The soft power off state will remain after a power cycle. Long pressing the power off button again will bring it out of soft power off mode.

**Switch temperature display**, pressing and releasing the power button quickly will switch which temperature probe's value is being shown on the display. If temperature from the secondary probe is showing an additional LED (between the first two digits) will be lit as an indication.

By pressing and holding 'up' button when temperature is showing, current setpoint will be displayed. 

By pressing and holding 'down' button when temperature is showing, *th* will be displayed if the controller is in thermostat mode or *PId* when in PID-mode. If a profile is running, it will cycle through *Prx* (where *x* is the profile number), current profile step and current profile duration, to indicate which profile is running and the progress made.

By pressing and holding 'up' and 'down' button simultaneously when temperature is showing, the firmware version number will be displayed.

# Development

STC-1000p-STM8 is written in C and compiled using IAR STM8 embedded workbench v3.10.4.

## Useful tips for development

* You will need the STM8S003F3 reference-manual (the datasheet merely lists the hardware related issues).

* The IAR STM8 Integrated Development Environment (IDE) has a code-size limit of 8 Kbytes. However, this is sufficient for our STM8 µC, since it only has 8 Kbytes of Flash memory.

* The IAR IDE organises the source-files in projects (.ewp) and workspaces (.eww). Use only 1 project per workspace. The default workspace file for STC-1000p-STM8 is stc1000p_dev.eww.

* A separate scheduler (non pre-emptive) has been added to address all timing issues. See the source files scheduler.c and scheduler.h

* Hardware routines (interrupts, ADC, eeprom) have all been rewritten from scratch, other routines have been copied and adapted from the stc1000p github repository.

* The eeprom of the STM8S003F3 only has 128 bytes on-board. Therefore only 4 profiles (instead of 6) with a maximum of 5 temperature time-pairs (instead of 9) are used. If you are willing to desolder this chip, you can replace it
with a **STM8S103F3** device, which has 640 bytes on-board. Setting the defines **NO_OF_PROFILES** and **NO_OF_TT_PAIRS** and proper initialisation of eedata[] (in stc1000plib.c) is sufficient to enable this.

* The processor type can be set using Project -> Options... -> General Options -> Target -> Device. This is necessary when you replace the stock **STM8S003F3** µC.

* If you want to add preprocessor defines (like Mats did), you can add these in Project -> Options... -> C/C++ Compiler -> Preprocessor -> Defined Symbols: (one per line). Currently I don't have any preprocessor directives in this version (but probably will for newer versions).

* HEX files (currently stored in subdir Debug/Exe) can be uploaded directly to the STC-1000 hardware with ST-Link v2 with the STVP program. The default route with IAR, Project->Rebuild All, then Ctrl-D (debug) also uploads the .hex file.

# Other resources

Project home at [Github](https://github.com/Emile666/stc1000_stm8/)

# Acknowledgements

Many thanks to Mats Staffansson (https://github.com/matsstaff/stc1000p) for initial development of a STC1000p on the A400_P hardware (containing a **PIC16F1828** microcontroller). The **STM8S003F3** device is a bit more advanced and I was intrigued by the idea of doing the same as Mats has done. In the end I ended with a few more features than he had (and also fewer, since he had more different firmwares).

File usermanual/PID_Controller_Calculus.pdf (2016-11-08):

PID Controller Calculus for STC1000p-STM8

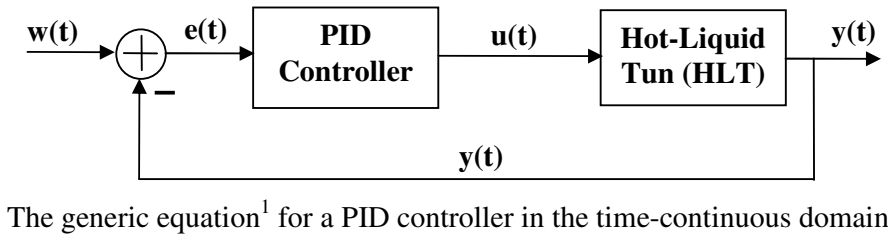
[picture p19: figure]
The generic equation¹; PID Controller; Hot-Liquid Tun (HLT)

Author: Emile van de Logt | Page 1/7

### 1. Introduction

This document describes the derivation of a PID controller that can be implemented in the STC1000p. The PID controller should be capable of controlling the temperature to within 0.1 °C.

This document contains the following information
- Chapter 2: the time-continuous representation for a PID controller
- Chapter 3: Derivation of an improved algorithm (a so-called ‘type C’ PID controller)
- Chapter 4: Description of algorithms for finding the optimum set of Kc, Ti

, Td and Ts
values for the PID controller

### 2. time-continuous representation of a PID controller

for a PID controller in the time-continuous domain is:

= | + | + ∫
dt

de t
dtte | T
T
tu | K | te | d

i

c

)(
)( | .

1
)( | )(. | (eq. 01)
With: Kc = Kp | Proportional Gain (for our temperature controller, unity is [% / °C])
Ti
= Kc / Ki | Time-constant Integral gain [sec.]
Td = Kd / Kc | Time-constant Derivative gain [sec.]
Ts | Sample period (default value is 20 seconds)
w(t) | Setpoint (SP) value for temperature
e(t) | error signal = setpoint w(t) – process variable y(t)
u(t) | PID output signal, also called Gamma, ranges from [0..100 %]
y(t) | process variable PV = measured temperature

### 3. Derivation of a Type C PID controller

There are three types of PID equations (see http://bestune.50megs.com/typeabc.htm) , with type C being the preferred one. Equation eq. 01 are type A equations, since the P- and the D-term both contain the setpoint. Any changes in the set-point may cause an unwanted change in the PID output u(t).
Removing the set-point from the D-term results in a type B controller. The type C controller has also removed the set-point from the P-term, resulting in an even better PID controller implementation.

Start with the generic equation for a PID controller again:

= | + | + ∫
dt

de t
dtte | T
T
tu | K | te | d

i

c

)(
)( | .

1
)( | )(. | (eq. 01)

1
This is the ideal, textbook version of a continuous-time PID controller. See “Digital Self-Tuning Controllers”, ISBN 1-85233-980-2, Bobál et.al., page 54.

Author: Emile van de Logt | Page 2/7

Now differentiate both sides:

= | + | + | 2

2
)(
)( | )(

)(
dt

d te
T
T

te
dt

de t
K
dt

du t

d
i

c

(eq. 02)

Now transform equation eq. 02 to the time-discrete domain, using backwards differentiation:

( | )
+ | + | − | +

−
+=

−

− | −
− | −
2 | 1 | 2

1 1
k

.2 k k

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
k | k
e | e | e
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
(eq. 03)

Equation eq.03 can now also be written as:
( | ) | ( | )
= | −1 + | − −1 + | + | −1 − | − | −2

.2.

k | k | k
s

d

i

ks
k | k | c | k | k
y | y | y
T

T
T

T e
u | u | K | e | e | (eq. 04)

Equation 04 is a type B equation, because the differential term no longer depends upon wk (remember that ek = wk – yk).

We will now transform equation eq.04 into a type C equation (eq. 05), by also removing the setpoint wk from the proportional part (again: ek = wk – yk):

( | )
= | −1 + | −1 − | + | + | −1 − | − | −2
. | . | .2.
k | k | k
s

d
k
i

s
k | k | c | k | k
y | y | y
T

T
e
T

T
u | u | K y | y | (eq. 05)

Here, yk is the process variable, which is the actual temperature of the HLT. This is the well-known relation given by Takahashi²
, also known as the Takahashi PID controller.

Equation 05 is used directly in pid_ctrl().

2
Y. Takahashi, C. Chan and D. Auslander, “Parametereinstellung bei linearen DDC-algorithmen”, Regelunstechnik und Prozessdatenverarbeitung, vol. 19, pp. 237-284, 1971

Author: Emile van de Logt | Page 3/7

### 4. Finding the optimum set of PID parameters

Finding the optimum parameters for a PID controller can be difficult. Optimum means that the set-point temperature is reached as quickly as possible with overshoot minimised.

Three well-known algorithms for determining the PID parameters are described here:
- Ziegler-Nichols open-loop: set PID controller to a certain output and determine slope and dead-time of HLT system
- Ziegler-Nichols closed-loop: measure step-response
- Cohen-Coon: also a closed-loop method. Measure step-response
- Integral of the time weighted absolute error (ITAE): results in the best performance. The error signal is minimised (over time).

Some terms are frequently used in this document:
- Dead-time θ: this is the time-delay between the initial step and a 10% increase in the process variable (the HLT temperature in our case).
- Khlt: the gain of the HLT-system. The HLT-system receives the Gamma value (PID output) as input and has the HLT temperature as output. Unity of Khlt is [°C / %].
- τhlt: the time-constant of the HLT-system. The HLT-system can be described with a first-order process model with time-delay (FOPTD). The transfer function for this model is:

. 1

)(

+

=

−

s

K e
HLT s

hlt

s
hlt
τ

θ

- a*: the normalised slope of the step response. Equal to ∆T / (∆t. ∆p) with:
- ∆T: change in temperature [°C]
- ∆t : change in time [seconds]
- ∆p: change in PID controller output [%]

With these three parameters, the optimum PID parameters are determined using table 1 on the next page (values are given both for PID operation and for PI-only operation):

Author: Emile van de Logt | Page 4/7
Method: / Parameter: | Kc [% / °C] | Ti [seconds] | Td [seconds]
Ziegler-Nichols Open-loop | 2,1 Kc = θ . * a | Ti = .0,2 θ | Td = .5,0 θ
Ziegler-Nichols Open-loop | 9,0 Kc = θ . * a | Ti = .33,3 θ | - -
Ziegler-Nichols Closed-loop | .2,1 τ hlt K = c θ K . hlt | Ti = .0,2 θ | Td = .5,0 θ
Ziegler-Nichols Closed-loop | .9,0 τ K = hlt c θ K . hlt | Ti = .33,3 θ | - -
Cohen-Coon | τ θ 4 hlt K = . + c K . θ .4 τ 3 hlt hlt | .32 τ + .6 θ hlt Ti = θ . .13 τ + .8 θ hlt | .4 τ hlt Td = θ . .2 θ + .11 τ hlt
Cohen-Coon | τ θ 9 hlt K = . + c K . θ .12 τ 10 hlt hlt | .30 τ + .3 θ hlt Ti = θ . .9 τ + .20 θ hlt | - -
ITAE-Load | − 947,0 357,1 θ K = . c K τ hlt hlt | 738,0 τ θ = hlt Ti . 842,0 τ hlt | 995,0 θ Td = 381,0 . τ hlt . τ hlt
ITAE-Load | − 977,0 859,0 θ K = . c K τ hlt hlt | 680,0 τ θ = hlt Ti . 674,0 τ hlt | - -

Table 1: optimum PID parameters for the various methods

To be able to find these three parameters accurately, two experiments need to be conducted. These two experiments are described in the next two paragraphs.
The last paragraph (§ 4.3) shows the calculated PID parameters for all these methods.

PID Controller Calculus for

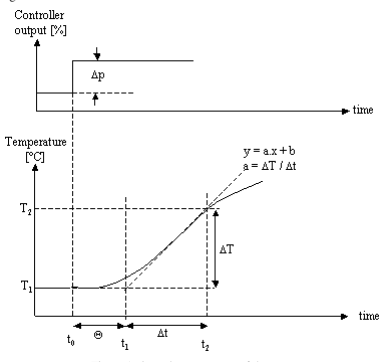
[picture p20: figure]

Author: Emile van de Logt

### 4.1 Experiment 1: Determine dead

Manually set the PID-controller output (“gamma”) to a certain value (e.g heavy load, 100 % is recommended (more acc
the system, a lower value to start with is better.
curve in figure 1.

Figure 1: Open

Calculate the average slope of the rise
Calculate the normalised slope a*, which is defined The dead-time θ is defined as the time between t done quite accurately).

Experimental data: HLT filled with 85 L water
19:08:20 | t0, the PID controller output gamma was set to 100 %,
| Step-response up to 55.00
19:12:25 | Thlt = 48,18 °C (≥ T
19:27:21 | Thlt = 54,25 °C (≥ T

Regression analysis of the data between 19
| y = a.x + b = 0,0334x + 48,278
Here, every data-point for x represents 5 seconds. Therefore, the av
| a = 0,0334 °C / 5 sec. = 6,68E
Now solve where this curve hits the Tenv line:
| x = (47.41 – 48.278) / 6.68E The dead-time moment is then 19:12:25
| Therefore, the dead

-time Θ of HLT
controller output (“gamma”) to a certain value (e.g. 20 %). In case of a urate), but if you don’t know the performance of The temperature starts to increase and follows the

Figure 1: Open-loop response of the system

(a = ∆T / ∆t) by using regression analysis if possible. as: a* = a / ∆p.

### 0 and t1 (by using regression analysis, this can be

, the PID controller output gamma was set to 100 %, T1 = 47,41 °C °C, ∆T = 7,59 °C
T1 + 10%.∆T = 48,17 °C)
T1 + 90%.∆T = 54,24 °C)

:12 :25 and 19:27 :21 resulted in the following: R²
= 0,9995
point for x represents 5 seconds. Therefore, the average slope a is equal to: C / 5 sec. = 6,68E-03 °C/second (which is 0,4 °C/minute)

-03 = -130 seconds (or 2 minutes and 10 seconds) time moment is then 19:12:25 – 2:10 = 19:10:15
-time θ = 19:10:15 – 19:08:20 = 1:55 = 115 seconds

Page 5/7

-system
. 20 %). In case of a

PID Controller Calculus for

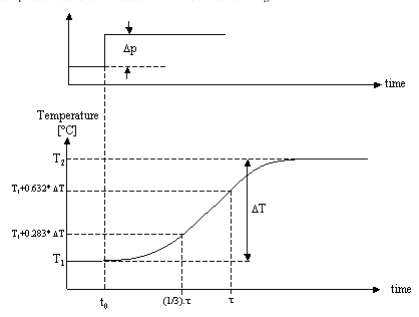
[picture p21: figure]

Author: Emile van de Logt

The normalised slope a* is equal to :
a* = a / ∆p = 6,68E

### 4.2 Experiment 2: Determine gain K

Manually set the PID-controller output temperature starts to increase and follows the curv

Because of the large time-constant presumably present in the HLT system, the not very accurate in determining the dead
experiments (theoretically, the step
determine the three parameters).

Experimental data: HLT filled with 85 L
09:49:04 | t0, the PID controller output gamma was set to 20 %,
20:24:03 | Experiment stopped, T = 52,98
Regression analysis (2
Maximum found at 21:20:44 (8300 ticks of 5 seconds) ∆T = 52,989 – 19,20 = 33,789
T(t = 1/3.τhlt) = T1
T(t = τhlt) = T1 + 0,632 *
Solve for τhlt:
Solve for Gain Khlt: | Khlt = ∆T /

:
-05 °C/(%.second)

hlt and time-constant τhlt (“gamma”) to a certain value (e.g. 20 %). The e in figure 2.

Figure 2: Step response of the system

constant presumably present in the HLT system, the -time θ. This is the mean reason to conduct two -response would give you all the required informatio

water
, the PID controller output gamma was set to 20 %, T1 = 19,20 °C °C.
nd order polynomial) used to find maximum. Maximum found at 21:20:44 (8300 ticks of 5 seconds). T2 = 52,989 °C 19,20 = 33,789 °C
+ 0,283 * ∆T = 28,762 °C => 1/3.τhlt = 6599 seconds
+ 0,632 * ∆T = 40,555 °C => τhlt = 16573 seconds τhlt – 1/3. τhlt = 16573 – 6599 => τhlt = 14961 seconds ∆p = 33,789 °C / 20 % = 1,689 °C / %

Page 6/7

hlt of HLT-system

step response is

n to

Author: Emile van de Logt | Page 7/7

### 4.3 Calculation of PID parameters for the various methods

In the previous paragraphs, the following parameters were found:
- | dead-time θ | = 115 seconds
- | Gain Khlt | = 1,689 °C / %
- | Time-constant τhlt | = 14961 seconds
- | Normalised slope a* | = a / ∆p = 6,68E-05 °C/(%.second)

Kc [%/°C] Ti [sec] Td [sec]
Ziegler-Nichols Open Loop | 156,2 | 230,0 | 57,5 PID
| 117,2 | 383,0 | - - PI
Ziegler-Nichols Closed Loop | 92,4 | 230,0 | 57,5 PID
| 69,3 | 383,0 | - - PI
Cohen-Coon | 102,8 | 282,2 | 41,8 PID
| 69,4 | 377,2 | - - PI
ITAE-Load | 80,8 | 489,0 | 44,9 PID
| 59,2 | 810,2 | - - PI
Table 2: Calculation of parameters for the various methods

Version History
Date | Version | Description
8-11-2016 | V0.1 | First version for Github STC1000p-STM8

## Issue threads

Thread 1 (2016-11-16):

Manually set pid-output to a fixed f

Emile666, 2016-11-16:

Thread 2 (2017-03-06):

Enter menu

adool88, 2017-03-06:
on 103f3 programmed with STVD can't enter menu. S button switches between some temps. S long press leads to Off. Another S long press leads to restart. If I quickly press up I enter menu (Pr1-...Pr5- Set), but S press leads to main screen and so on. Help! :)

Emile666, 2017-03-07:
I assume you removed the 003f3 device and resoldered an 103f3 device? At least that is what I conclude from your post. Could it be that there a pins soldered together? Or shorted? Did you measure all pins to not connect to each-other?

In other words: make sure that the hardware connections are oke.

adool88, 2017-03-07:
Hi,

Thanks for response.
Yes, chip resoldered ( to 103f3). Twice.
Will measure, but at least under microscope it looks ok.
I also soldered 3 pieces of 4.7k resistors (R25, 26, 27 or so) on mainboard. Two of them are not connected to any trace. I have new version board, all mods are done as per your description.

BR,
Darius Stauskas

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

adool88, 2017-03-07:
Hi,

Found solder joint on buttons.
Everything works now as expected.
Sorry for false alarm and BIG thanks for software.

BR,
Darius Stauskas

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

Emile666, 2017-03-07:
No problem! Glad to hear that it was hardware related!

Closed 2017-03-07.

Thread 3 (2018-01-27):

Flashed but OFF showing

Perimec, 2018-01-27:
Hi,
thanks a lot for your code... however I have flashed it and I get OFF all the time. I have tried to flash it several time but always the same error. Could it be something with the software?

thanks

Emile666, 2018-04-01:
I can only think of the eeprom being wrong. Have you flashed the correct .hex file? If you flashed the 103 version and have the 003 hardware, that could be a problem.

Alternatively: what if you press the PWR button for a few seconds? The stc1000 should get back to a normal state.

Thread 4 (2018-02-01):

Feature request: Communication protocol

Highcooley, 2018-02-01:
Could you please implement a communication protocol like Mats did on the pic version to read/write temperature as well as settings with an external controller? I plan to attach an IoT controller for remote control purposes, logging as well as having a graphical UI.

Emile666, 2018-04-01:
This is difficult to do for two reasons:
1) Hardware. The stock microcontroller has an UART connected to PD5 (UART1_TX) and PD6 (UART1_RX). Both pins are currently in use. If you give up the buzzer (now connected to PD6) and the new PID/SSR feature, you could implement this. In my opinion, the PID/SSR functionality is more useful than UART communication. But still: you need a new frontpanel PCB and that's not what most people are willing to do for this project.
2) Software. We only have 8K and pretty much everything is taken, since I already added most of Mats separate options in this firmware. UART communication with a command-interpreter is pretty substantial and would not fit in the remaining flash memory.

So: not feasible with the current hardware and software. But have a look at my other project: 'stc1000p on steroids'. That one has UART communications (and lots of other stuff).

Closed 2018-04-01.

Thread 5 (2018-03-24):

PID output decimal dot

zstomp, 2018-03-24:
In PID output display mode (PWR button pressed twice), decimal dot is not showing. I think it would be less confusing if it showed.

Emile666, 2018-04-01:
Good point! Initially I calculated pid_output as a percentage, but since all temperatures are in E-1 °C, it was more convenient to also calculate pid_out in E-1 (%). I can do two things:
- Drop the E-1 % and display pid_out in %
- Display it as E-1 % with a dot (e.g. 85.3) and display 100 % as '100'
Any comments on these two options? What do you prefer?

zstomp, 2018-04-02:
I think I'm a little bit more inclined towards second option. And thanks for the awesome firmware!

Closed 2018-04-07.

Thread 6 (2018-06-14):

STC is getting really warm

tjarmann, 2018-06-14:
I have two STCs with the STM8S003F3, and I upgraded them before testing them. Now, I notice that they are getting a lot warmer than other STCs I have (the one matsstaff fiddled with). I insulated my probe and stuck it in the STC case, and it is measuring~50 C. Is this normal? Are these STCs like this regardless of the firmware? I feel reluctant to enclosing this in a box and having it on for weeks..
The probe is not calibrated, but i can feel the heat coming of the STC.
There is no load on the relays.
I have two probes connected to the STC, and the ambient temperature is (uncalibrated) ~20 C.

Update: Inside the case, close to the little transformer, I now read 72 C. It's been running (still without load on the relays) for four hours.

I am new to github and have no idea how I should contact you, so this is how i chose to do it. I am sorry if it is the wrong way.

Emile666, 2018-06-17:
Tjarmann,

I have never noticed any problems with the power-supply of these devices. However: the power-supply on the board is pretty small and can only deliver a small amount of power. But again: never had a problem with it. Fifty degrees is about normal I would say, it should not get above 80 degrees. It is very well possible that with my firmware the device has to work harder and thus draws a bit more power.

I would say that it is good to keep an eye on it, but don't worry too much about it.

Regards,

Emile van de Logt

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

tjarmann, 2018-08-07:
I finally got a hold of a FLIR camera and checked the STC out. The tiny transformer is definitely the culprit, heating up to 140C. I doubt this has to do with your firmware. The label on my STC says 110-220V, but my outlet is 230V. I'm guessing that my device has a transformer that is badly scaled for 230V operations.

Anyway, thank you for your response :)

Closed 2020-03-15.

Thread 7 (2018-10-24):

PID stopped working

zstomp, 2018-10-24:
PID output is stuck at 0. In thermostat mode, heating gets turned on. It worked fine the last time I used it, and no hardware or setting change was made. Any ideas? Thanks!

UPDATE:
After I manually turned the heating on and the temperature increased, PID kicked in.

zstomp, 2018-10-25:
It seems to be working now, not sure what was wrong. Perhaps higher ambient temperature affected it?

Closed 2018-10-25.

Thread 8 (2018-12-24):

/set/sp does not actually effect the conroller loop

owenduffy, 2018-12-24:
It seems that using the menu to set SP in th mode does does not actually set the SP, though it stores it.

The only way I found to fully set a SP is to make a profile with SP0 what I desire, and dh0=0, and it immediately expires and passes the SP into the th mode, and the controller works as it should.

I thought from the docco that I could ignore prfofiles and simply set th run mode, ts=0 to disable PID, and SP etc for the working 'single stage' operation.

Owen

owenduffy, 2018-12-26:
False alarm.... apologies. It turned out the DATA tab was not loading properly, so it was not intialising EEPROM correctly. Seems ok after making sure it does load EEPROM.

Closed 2018-12-26.

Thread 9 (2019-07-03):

One vessel brew system controller firmware

technoicon, 2019-07-03:
is there any way to use the OVBSC firmware on this device.

I found out I had this device and would like to use it to control a pump.
I have a 3V system, and just want to use the STC as a timer to start the brew day the night before, then heat the HLT, then start mash in.

For example:
Set profile 1 - 10 C for 8 hours (delay start for 8 hours), profile 2 - 75C for 2 hours (heat to 75C), start pump for 5 mins (transfer hlt to mash tun).

I've done basic php programming but never programmed these types of devices.  Would this be hard to program?

Your system doesn't say anything about controlling a pump?

Any feedback or ideas would be great thanks.  (even if its just that I need to get the right STC-1000).

Emile666, 2019-07-09:
I didn't migrate the OBVSC firmware from Mats, as I have a 3V system with its own dedicated electronics. Mats has a nice description of the OBVSC algorithm that he implemented. He uses the two relay outputs for heating and uses the unpopulated terminal for pump control. If you want to migrate his code, you have to have a decent knowledge of the C programming language. I made a lot of changes to Mats code, to fit it in the STM8 uC. So you have to dive into both Mats' code and my code and merge that into an OBVSC firmware.

For now: it would be best to obtain a PIC version of the STC-1000, if they still exist, and use Mats' OBVSC firmware.

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

Emile666, 2020-03-15:
Since about a week, I am working on this! Current version is ready for testing, meaning it still should be debugged.

Taimie44, 2023-04-08:
Hi, great work!
I see that you have uploaded the manual for the OVBSC version.
Would it be possible to also upload the ovbsc firmware to try it out on the stc-1000?

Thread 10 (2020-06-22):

New hardware issue

owenduffy, 2020-06-22:
Hi, I had problems programming a newer version of the STC-1000. Solution given at https://owenduffy.net/blog/?p=18048 .
I did not try, but it may have been possible to program the original unlabelled chip once C2 was fitted. By the time I had removed the front panel board, I might as well replace the MCU.
You are welcome to use any of the content for this repo or associated wiki.

Owen

matsstaff, 2020-06-22:
Interesting find! Thanks for sharing!

Closed 2020-06-22.

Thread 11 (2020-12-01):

Some question for external monitoring

vetsolution, 2020-12-01:
Hello,
First of all thank you for your work, especially for the inversion of electronic diagrams
I would like to use an esp32, to monitor my fermentation chamber. I already have an esp32 with a ds18b20 sensor which sends me the temperature every 10sec.

I want to know the status of the cooling and heating relays. So I think there are two ways to handle it:

    1. Use pins 5 and 6 which trigger the transistors of the relays?
    2. Use the LED signal on the front panel, but I don't know where it is. I'm assuming there is some sort of multiplexing for display management (I2c?)? Can you describe the input of the 7-segment display DIS1?

What do you think is the best way to manage it?
If I use the first choice I guess I can't pin this to esp32, the best way is to use a transistor or divider bridge (5v-> 3.3v)

Do you have the reference of the temperature sensor? Where is it on the diagram?
Finally, do you have a quick explanation of what it is: SWIM_4, NTC1, NTC2, CC1, CC2, CC3, CC4, S3
SWIM_S4 is some kind of debugging channel? but why is it connected to the screen?
CC1 and CC2 is an I2c bus to control the display?
NTC1, NTC2 is the temperature sensor? Why is it also wired to the screen?

Thank you

lalo-uy, 2020-12-02:
If you gone put an esp32 to the task, why no not program Brewpiless on it???
An option just to monitoring is to use a serial feed on the spare line used
for the optional pwm.

El El mar, 1 de dic. de 2020 a la(s) 20:54, Patz Michel <
notifications@github.com> escribió:

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

vetsolution, 2020-12-02:
I do not want to flash the stock firmware.
Just keep it as it is and monitor the relay and send result via mqtt to https://io.adafruit.com
And better undestand the STC1000 ;)
I will read mor about Brewpiless but I think that is a bit overkill for my need

Emile666, 2020-12-02:
@vetsolution If you want to know the status of the relays, simply attach something to the HEAT and COOL lines. They are direct outputs of the STM8 and go to the backplane to the transistors that switch the relays on and off. Best is if you solder some thin wires on the base resistors on the backplane.

The LEDs are integrated in the 7-segment display. The 3-digit 7-segment display is in fact a 4-digit display, the 4th digit is for all the individual leds, such as °C and the heating and cooling leds. Since this is multiplexed, you cannot access these directly.

vetsolution, 2020-12-02:
I see, thanks for the info about the display!
I will try a setup like this but I am not sure about resistance values
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

lalo-uy, 2021-01-02:
The values you placed are ok.

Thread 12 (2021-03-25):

New rev V2

radim100, 2021-03-25:

lalo-uy, 2021-03-25:
May you upload photos of both sides of the boards?

radim100, 2021-03-25:
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

radim100, 2021-03-25:
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
 SWIM Pins + GND1

radim100, 2021-03-25:
![Uploading 20210325_170302.jpg…]()
![Uploading 20210325_170314.jpg…]()

radim100, 2021-03-25:
I have added 10k resistor from RST to VCC since reset was sitting at GND

lalo-uy, 2021-03-26:
It is hard to tell without checking continuity with a tester.
My bet is that the 74164 outputs goes tho display pins 5 to 12.
The cpu loads the shift register with data on pin 1&2 and clock on pin 8.
You need to check where in the cpu are that pins connected.
In the original hw the display pins are used also for input functions,
ntc1&2 and buttons. In this hw the functions are not multiplexed,
simplifying the software.

El El jue, 25 de mar. de 2021 a la(s) 20:05, Radim Stepanik <
***@***.***> escribió:

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

radim100, 2021-03-26:
Hello Eduardo and thanks for reply .
Yes I agree with 74HC164D shift register functionality .

My problem is that so far I could not communicate with STM8 neither from STVP or IAR debugger / programmer .

I have modified following so far :
1. pull up 10k on RST
2. Pull up 2k7 on SWIM
3. Originally VCAP capacitor was not populated so I have added 1uF
4. Originally 10nF cap on RST was not populated - added

I have checked some connections
1. PIN  18 of uC is connected to SIG pin on 5 pin front header ( SWIM signal ). It is also shared with DOWN push button .
2. PIN 4 of uC is connected to RST pin on 5 pin front header ( /RST signal )
3. GND1 on 5 pin header is connected to VCAP
I power front board USB ST-Link  ( 3.3 V or 5.0V ) the same result - display powers up OK
I have verified that ST-Link works on another board with similar STM8L051 uC , verified reading and writing from STVP and IAR .

Is there any HW R/W protection of this uC I have to enable before communicating with SWIM debugger ?

radim100, 2021-03-26:
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
This is error screen I get

Emile666, 2021-03-27:
I have not seen this HW version before. Last ones I bought were all with a Nuvoton N76e003at20 uC. Were did you buy this version? Can you try the STVP suggestion from the dialog box? With NRST forced low. I have not seen this protection before. Only one I had was the read-out protection. I am interested to hear some more. Maybe I can adjust the firmware, so that it works with the HC164 device.

radim100, 2021-03-27:
Hello Eduardo , Thanks for your reply
I have bought this one from Amazon :

https://www.amazon.ca/gp/product/B07SFM44WS/ref=ppx_yo_dt_b_asin_title_o02_s00?ie=UTF8&psc=1

The uC on chip print is removed so I cannot say for sure what uC is used . I just guessed that if SWIM header is present and
SWIM, RST, VCC, GND signals have continuity check to corresponding pins on uC that it is STM8 family chip .
Based on your experience with Nuvoton chips , are they direct pin-pin replacement for STM8 . I was under impression that Nuvoton is using different ICP signals .

Regarding to STVP suggestion with holding NRST low during  power On , yes I have tried this with no success .
I like HC164 chip use since it would release lots of pins of uC . Our goal is to preserve as much as possible HW from original
STC-1000 and somehow attach ESP8266 or ESP32 module to it for WiFI MQTT connectivity to regulator .
Also ( of course ) it is challenging project :-) :-)
Thanks for your interest and help

lalo-uy, 2021-03-28:
I wuld like that too.
Setint some form of commands in/out on the serial will be enough to hook it
 to a Tasmota for mqtt connectivity.

El El sáb, 27 de mar. de 2021 a la(s) 20:05, Radim Stepanik <
***@***.***> escribió:

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

radim100, 2021-03-28:
Hi Eduardo , I have ordered second STC-1000 from different vendor on Amazon . Hopefully it will be older version with  STM8
Should have it on Monday . I will let you know .

radim100, 2021-03-29:
Hi Eduardo ,
My second STC1000 arrived but it is completely different than others .  It has Nuvoton MS51FB uC , hiding under LCD :-)
See some attached pictures . It is hard to figure out from what supplier what version would come .
I saw you have some STM8F105 PCB from Eagel design . Are those open source or private ?

radim100, 2021-03-29:
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

Emile666, 2021-03-30:
I made a frontpanel and a backplane in Eagle: it reuses the 7-segment display. Problem is that newer stc-1000s, with the nuvoton uC, sometimes ship with a CA 7-segment display. So I updated my frontpanel and added a MCP23017 IC that controls the 7-segment display, no matter if it is CA or CC. With the MCP23017, the CA or CC option can be set in software.

I also made a frontpanel version with the stm8s105 uC: this one has more IO and also includes an one-wire (DS18B20) temperature sensor interface, uart comms and I2C. To have this available at the back, you also need a new backplane pcb.
So I reuse the stc-1000 casing, the terminals, the relays and the 7-segment display, but add a new frontpanel PCB and a new backplane PCB. The version with the STM8S103 and MCP23017 closely resembles the original stc-1000, the stm8s105 has lots of features added.

I have no problem making these boards available here, but you also need the specific firmware for it. I have to find out how to do all that in a logical way in Github (hardware boards + firmware). I will probably make a new project (or 2, even better) for this.

radim100, 2021-03-30:
Hi Eduardo ,
Thanks for your information . Yes , unless we deal directly with manufacturer , there is no guarantee that we get the same HW all the time . I will be following your posts on this repo and looking forward for future addons .
Our goal is to make plug in replacement for industrial freezer which already use STC-1000 . So save on cost we were planning to
attach ESp8266/ESP32 to existing hw . But we may as well redesign both PCBs and use ESP as main micro .

dnoha, 2022-07-27:
> Our goal is to make plug in replacement for industrial freezer which already use STC-1000 . So save on cost we were planning to
> attach ESp8266/ESP32 to existing hw . But we may as well redesign both PCBs and use ESP as main micro .

Any progress about attaching ESP to existing HW?

I also have now one STC with microcontroller behind LCD. No idea what it is, just hoping I can monitor and control over serial port. Hopefully ESP with Tasmota firmware which should just forward commands from mqtt to serial port, and back.

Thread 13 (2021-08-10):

Off-Grid Solar Refrigerator

mbr1989, 2021-08-10:
Hi,

could you write me a firmware with which you can use the heating output to switch on the 230V inverter ?

best regards
Marcus

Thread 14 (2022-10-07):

Temperature sensors not showing real values

ffpp2003, 2022-10-07:
I've got this STC-1000 that has the same box as emile (like the WR-032-v1), but has a different PCB name. This one is the XD-1000-v1.0. The backplane looks to be pretty similar to the WR-032 v2[ board ](https://github.com/Emile666/stc1000_stm8/blob/master/WR-032-v2-2016-4-7.md#new-hardware-revision-wr-032-v2). The only difference that i was able to find is that this version (compared to the WR-032-v1) uses the UFQFPN20 package of the STM8S003F3, while also having the pads and silkscreen for the TSSOP20 version of the same chip. I'll add some photos of the front-pcb and the power pcb.
The problem i'm experimenting is that temperatures do not get read properly, in the sense that both numbers (NTC1 and NTC2) start at 25cº, but the NTC1 starts to raise up and the NTC2 starts to go down, until they stabilize at 40cº and 1cº respectively. I only plan to use this STC with one temperature probe, and no SSR or any extra mod.
I've tried using IAR to reduce or even disable the number of averaged measurments, but it seems to have no change at all.
What else can i try to fix this problem??
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

Emile666, 2022-10-08:
I checked the datasheets of both packages and they look the same. Interesting way of combining these 2 packages, I have not seen it before. The NTC1 and NTC2 readings go to pin 20 (NTC1, AIN4/PD3) and pin 19 (NTC2, AIN3/PD2). This is the same as on the QFPN package.
Can you check if the voltages show up at pin 19 and pin 20 when you connect the sensor inputs to GND and VCC? That should be 0V and 3.3V respectively (leave the sensors off).
Since these temperaturesensors are multiplexed with the A and B leds of the display, can you check if the display is really Common-Cathode (CC)? If it is common-anode, this could be the cause of the problem.

ffpp2003, 2022-10-08:
So, i did what you told me to do. When floating (nothing connected on the screw terminal) i get from 3.3v to 4.5v. Thats what i was able to measure with my multimeter. I could get to have an oscilloscope, but it will be in some days, when i go back to work.
When the screw terminal is connected to GND, the shown temperature starts to go down in a slow manner, like 1 to 1.5c per second. Measuring pin 20 (not actually pin 20, but the 1K resistor that is on the big PCB, touching of course the side that connects directly to the pin20) i get from 1.1v to 2.3v.
Connecting the screw terminal to 5V i get voltages from 3.3v to 4.5 and ocassionaly dipping to 2.3v.
I did all tests using the mains power supply and also using the STLINK voltage lines, to have a clean power source and a noisy one. Both tests gave similar results
Checking the 7segment display, its the same as in the schematic. Pins 1 and 2 are connected to vcc through 5.1K resistors and pins 3 and 4 are connected to pins 1 and 2 of the tssop pads, and connected to the respective pins on the qfpn pads. This test i think was unecessary because if it was the wrong common, all segments would be inverted, which is not the case.
So, no hardware issues from what i can see. What could it be??

Emile666, 2022-10-10:
What I can see from your picture is that R23 and R24 are not populated, so the NTC2 value is not connected to the microcontroller. That explains why your NTC2 reading is not working. If you want to have proper NTC2 values, you need to solder these two resistors back in place. R23 should be 10 kOhm (103) and R24 should be 1 kOhm (102).

W.r.t. the NTC1 reading, it could be that the C8 capacitor (between R21 and R22) is the problem. Simply remove this capacitor and the NTC1 reading will probably be oke.

Can you try this and let me know if that works?

ffpp2003, 2022-10-10:
Yes! Removing C8 did the trick! now it works perfectly fine. I tested it with my hot air gun and with an ice cube and it works perfectly fine. I would've never figured it out by myself. The weird thing is that the capacitor seems to be allright. I measured its capacitance with my multimeter and it gives 106nF, which is between the 5% tolerance. So, thats weird.

Also, now that you've talked about NTC2, i want to ask you, is there a way to "completely remove" NTC2 from the firmware? Like, in the orignal STC1000+, there is a "flavor" which only has NTC1. Peeking around the source code, i wasnt able to find a macro or a define that specifically says "NTC2", where setting it to false disables and removes everything related to NTC2 from the firmware. I guess if there isnt something like that, the only way would be to manually remove all those parts from the code, but i was just wondering if there is that firmware "flavor" thing on your port.

Anyway, thanks for helping and sharing this awesome mod!

Emile666, 2022-10-11:
There is no such thing as a macro for that. Instead the parameter Pb2 is used for this. If you set this value to 0, the 2nd temperature probe is not used in the firmware. So you can enable/disable this run-time with the keys on the front. The original firmware needed to do this because of very limited available memory. The STM8 has a bit more memory, so I choose to add this as a parameter instead of a macro.

I would suggest to leave it to 1 and populate the missing resistors, since the firmware then uses the outside temperature to determine whether or not to enable heating/cooling. If outside temperature is warm enough, heating is not enabled. Same for cooling: if outside temperature is cool enough, cooling is not enabled. This prevents heating/cooling cycles and saves you energy.

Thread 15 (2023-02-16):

New rev wr-32 v3

levshinovsky, 2023-02-16:
I received STC-1000 WR-032 V3.
It is very different from others.
LED display (no identification ) looks the same, but only has 7 pins.
Only one 16-pin mc  (no identification ) on front board ( behind LCD).
SWIM interface has SIG , RST , VDD, GND , GND1 (may be stm8?)
I checked it witn a St-link v2 - "Cannot communicate with the target"
(Communication features - SIG & RST pins connected to the same mc pins with 2 & 3 (left to right) pins of LED)
Controller type - do you have any ideas?

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

levshinovsky, 2023-02-16:
Additional communication features - GND1 pin connected to the same mc pins with 1 (left to right) pins of LED)

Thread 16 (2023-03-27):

PID for heating, bang-bang for cooling

guestisp, 2023-03-27:
Is possible to use the PID mode just for the heating output (a heating cable) and standard bang-bang mode for the cooling device (a peltier cell that wouldn't work in PID mode) ?

guestisp, 2023-03-30:
Oh, great.
So, as I have to buy an STC1000 trying to have a PID control for the heater and a standard bang-bang for the cooling, if you are planning to release this feature in the next firmware, i'll buy one controller.

Which one do you suggest (from amazon) ?

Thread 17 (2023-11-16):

PID for peltier

JasperBFH, 2023-11-16:
Hi,

I am developing a PID temperature controller for controlling temperature using a peltier element and an H-bridge.
The H-bridge is controlled using 2 PWM signals. Heating is faster than cooling, so 2 PID controllers are needed because the parameters are different. I used your PID code, but Kc is never set in the software?

Furthermore,
can you give me a tip how I can heat from 10 to 15 degrees and then stay at 15 degrees and the temperature does not rise due to room temperature

Closed 2023-11-16.

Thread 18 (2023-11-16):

PID Tuning peltier

JasperBFH, 2023-11-16:
Good afternoon,

I came across your github and I see that you are very experienced in realizing PID controllers.
I am working on creating a PID controller for controlling the water temperature using a peltier, H-bridge and PID.
The PID for heating has been tuned using your document PID_Controller_Calculus.
I have also tried this with cooling, but this does not work at all. Can you help me to tune the PID for cooling.

lalo-uy, 2023-11-20:
For the cooling side, if you use chiller an recirculating pump or electro
valves, you ca use a very slow pwm, 1 minute period or even more.

El El lun, 20 nov. 2023 a la(s) 13:11, Emile ***@***.***>
escribió:

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

JasperBFH, 2023-11-21:
I control the H-bridge with a PWM of 20KHz. The sample time for the PID algorithm is 3 seconds. With the help of Ziegler Nichlos and pidtuner.com i determined my parameters for heating & cooling.

Cooling Kp= 175, Ki = 1.45,     Kd = 0,
Heating Kp = 20,  Ki = 0.0889, Kd = 0,

I tried your type C Takashi PID controller. Unfortunately I'm getting crazy results with your code. I used a different PID code and it does produce the desired results.

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

What am I doing wrong? Surely a better PID controller (Type C Takashi) should work and not change the parameters?

    float PID_Update (PIDController *PID, float setpoint, float measurement
    {
    // Calculate Error
    float error = setpoint - measurement;

    //Calculate the integral error
    pid->integrator = pid->integrator + pid->Ki  * error;

    //calculate the measurement derivative
    float dpv = (measurement - pid->prevMeasurement);

    //calculate the PID output
    pid->P  = pid->Kp * error;
    pid->I  = pid->integrator;
    pid->D  = -pid->Kd * dpv;
    pid->out = pid->P + pid->I + pid->D;

    // implement anti-reset windup
    if (pid->out > pid->limMax)
    {
        pid->I =  pid->I - pid->Ki  * error;
        pid->integrator = pid->I;
        pid->out = pid->limMax;
    }
    else if (pid->out < pid->limMin)
    {
        pid->I =  pid->I - pid->Ki  * error;
        pid->integrator = pid->I;
        pid->out = pid->limMin;
    }

    pid->prevMeasurement = measurement;
    return pid->out;}

JasperBFH, 2023-11-21:
I guess the problem is in the PID algorithm. I will solve this myself to realize it for heating and cooling.

I do have one more question. If I start heating with the PID for heating, do I have to use the PID for cooling to make the calculations for cooling in the background so that the integrator adjusts when the temperature rises again

Emile666, 2023-11-21:
There's a define GMA_LLIM that is currently set to 0, but if you set this to -1000, it will do cooling as well. You only have to add some code that a negative output is sent to the Peltier element (as a positive percentage), and that a positive output is sent to the heating element as usual. In this way you can do a step-response as described in the document.

JasperBFH, 2023-11-24:
Okay, that's clear. The problem I am experiencing is that the P value is negative and therefore the system/PID controller does nothing when heating with the formula
pid->P = pid->Kp * (pid->xk_1 - xk) I get negative numbers.

If xk_1 is 25 degrees and xk = 26 degrees then you get a value of 20 * (25 - 26) = -20

This is strange if the set point is 30 degrees and the system needs to heat up. Then it seems to me that the P value must be positive?

Emile666, 2023-11-24:
My PID function is a type C velocity algorithm, it calculates a **delta,** so it is perfectly normal to get negative numbers, meaning that the PID-output should be decreased. The PID-output can still be positive, but it is getting a lower value. And since the setpoint is removed from the P and D action, it is less obvious to see. If xk_1 - xk < 0 in your case, then xk_1 < xk, meaning that ek < ek_1, which indicates that the error-value is decreasing. And therefore it is logical that the PID delta is less than 0, so that the PID output will be decreased as well.

JasperBFH, 2023-11-27:
Okay. Hmm okay, that's clear. But the problem remains that the output with PID never starts up. Like your example in the brewing process where the output goes to 100% when starting.

My tuned/calculated parameters (with the other PID algorithm) Kp, Ti, Td, Ts values   are 20, 239, 0, 3.

If I run the PID algorithm for the first time with room temperature then it is
Kp = 20 * (0-22.09)
Kp = -441.875

Ki = 0.25 * (30 - 22.09)
Ki = 1.98

Kd = 0

Out += P + I + D
Out = 0

the PID returns 0 and the water will never heat. What am I doing wrong?

Closed 2023-11-20.

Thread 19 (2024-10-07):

New Hardware Revision Controller Board 032-1.0

rsp-git, 2024-10-07:
Hello,
i bricked my old one with 032-0.0 and ordered a new one.
Now its without SWIM Connector and now there are 2 ICs under the Display.
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

Do you have an Idea if this is still a STM8? The ICs are cleaned.

BR

Emile666, 2024-10-07:
I don't think so. This is probably one of these Chinese 8051 clones, that they use a lot nowawadays. The display is also interesting, only 7 pins? I am probably missing something here. Also the solder connector is quite different from the original stc1000. What  I typically do is replace both PCBs with custom ones including an STM8s105. And I reuse components like casing and display. But that will probably not work here, since the display is too different.

gzalo, 2025-04-15:
The display seems to be charliplexed or something similar, with 7 pins it should be able to control up to 42 LEDs (and there are less in the display). If you try capturing it with a camera in slow motion you see odd artifacts, as segments light app in random order.

Were you able to identify the main microcontroller? I'm assumming it's OTP but we can dream. The 8 chip IC seems to be a 24Cxx memory, the pinout fits

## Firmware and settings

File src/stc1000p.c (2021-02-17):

/*==================================================================
  File Name    : stc1000p.c
  Author       : Mats Staffansson / Emile
  ------------------------------------------------------------------
  Purpose : This files contains the main() function and all the 
            hardware related functions for the STM8 uC.
            It is meant for the STC1000 thermostat hardware WR-032.
            
            The original source is created by Mats Staffansson and
            adapted for the STM8S uC by Emile
  ------------------------------------------------------------------
  STC1000+ is free software: you can redistribute it and/or modify
  it under the terms of the GNU General Public License as published by
  the Free Software Foundation, either version 3 of the License, or
  (at your option) any later version.
 
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
  You should have received a copy of the GNU General Public License
  along with STC1000+.  If not, see <http://www.gnu.org/licenses/>.
  ==================================================================
*/ 
#include <intrinsics.h> 
#include "stc1000p.h"
#include "stc1000p_lib.h"
#include "scheduler.h"
#include "adc.h"
#include "eep.h"

// Global variables
bool      ad_err1 = false; // used for adc range checking
bool      ad_err2 = false; // used for adc range checking
uint8_t   probe2  = 0;     // cached flag indicating whether 2nd probe is active
bool      show_sa_alarm = false; // true = display alarm
bool      sound_alarm   = false; // true = sound alarm
bool      ad_ch   = false; // used in adc_task()
uint16_t  ad_ntc1 = (512L << FILTER_SHIFT);
uint16_t  ad_ntc2 = (512L << FILTER_SHIFT);
int16_t   temp_ntc1;         // The temperature in E-1 °C from NTC probe 1
int16_t   temp_ntc2;         // The temperature in E-1 °C from NTC probe 2
uint8_t   mpx_nr = 0;        // Used in multiplexer() function
// When in SWIM Debug Mode, PD1/SWIM needs to be disabled (= no IO)
uint8_t   portd_leds;        // Contains define PORTD_LEDS
uint8_t   portb, portc, portd, b;// Needed for save_display_state() and restore_display_state()
int16_t   pwr_on_tmr = 1000;     // Needed for 7-segment display test

// External variables, defined in other files
extern uint8_t led_e;                 // value of extra LEDs
extern uint8_t led_10, led_1, led_01; // values of 10s, 1s and 0.1s
extern bool    pwr_on;           // True = power ON, False = power OFF
extern uint8_t sensor2_selected; // DOWN button pressed < 3 sec. shows 2nd temperature / pid_output
extern bool    minutes;          // timing control: false = hours, true = minutes
extern bool    menu_is_idle;     // No menus in STD active
extern bool    fahrenheit;       // false = Celsius, true = Fahrenheit
extern uint16_t cooling_delay;   // Initial cooling delay
extern uint16_t heating_delay;   // Initial heating delay
extern int16_t  setpoint;        // local copy of SP variable
extern int16_t  kc;              // Parameter value for Kc value in %/°C
extern uint8_t  ts;              // Parameter value for sample time [sec.]
extern int16_t  pid_out;         // Output from PID controller in E-1 %

#if defined(OVBSC)
extern uint8_t  prg_state;
extern uint8_t  al_led_10, al_led_1, al_led_01;  // values of 10s, 1s and 0.1s
extern bool     ovbsc_pid_on;
extern bool     ovbsc_pump_on;
extern bool     ovbsc_run_prg;
extern uint16_t countdown;
#endif

/*-----------------------------------------------------------------------------
  Purpose  : This routine saves the current state of the 7-segment display.
             This is necessary since the buttons, but also the AD-channels,
             share the same GPIO bits.
             It uses the global variables portb, portc and portd.
  Variables: -
  Returns  : -
  ---------------------------------------------------------------------------*/
void save_display_state(void)
{
    // Save registers that interferes with LEDs and AD-channels
    portb   = PB_IDR & (CC_10 | CC_1); // Common-Cathode for 10s and 1s
    portc   = PC_IDR & BUTTONS;        // LEDs connected to buttons 
    // Common-Cathode for 0.1s and extras and AD-channels AIN4 and AIN3
    portd   = PD_IDR & (CC_01 | CC_e | AD_CHANNELS); 
    PB_ODR |= (CC_10 | CC_1);  // Disable common-cathode for 10s and 1s
    PD_ODR |= (CC_01 | CC_e);  // Disable common-cathode for 0.1s and extras
} // save_display_state()

/*-----------------------------------------------------------------------------
  Purpose  : This routine restores the current state of the 7-segment display.
             This is necessary since the buttons, but also the AD-channels,
             share the same GPIO bits.
             It uses the global variables portb, portc and portd.
  Variables: -
  Returns  : -
  ---------------------------------------------------------------------------*/
void restore_display_state(void)
{
    PD_ODR &= ~(CC_01 | CC_e | AD_CHANNELS); // init. CC_01, CC_e and AD-channels
    PD_ODR |= portd;                         // restore values for PORTD
    PC_ODR &= ~BUTTONS;                      // init. buttons
    PC_ODR |= portc;                         // restore values for PORTC
    PB_ODR &= ~(CC_10 | CC_1);               // init. CC_10 and CC_1
    PB_ODR |= portb;                         // restore values for PORTB
} // restore_display_state()

/*-----------------------------------------------------------------------------
  Purpose  : This routine multiplexes the 4 segments of the 7-segment displays.
             It runs at 1 kHz, so there's a full update after every 4 msec.
             There is a preprocessor directive important here:
  Variables: -
  Returns  : -
  ---------------------------------------------------------------------------*/
void multiplexer(void)
{
    uint8_t led_4 = LED_OFF;
    // The default 7-segment display up until 2020 was Common-Cathode
    // Make CC 1 and a single segment 0 to disable LED
    PC_ODR    &= ~PORTC_LEDS;    // Clear LEDs
    PD_ODR    &= ~portd_leds;    // Clear LEDs
    PB_ODR    |= (CC_10 | CC_1); // Disable common-cathode for 10s and 1s
    PD_ODR    |= (CC_01 | CC_e); // Disable common-cathode for 0.1s and extras

    switch (mpx_nr)
    {
        case 0: // output 10s digit
            PC_ODR |= (led_10 & PORTC_LEDS);        // Update PC7..PC3
            PD_ODR |= ((led_10 << 1) & portd_leds); // Update PD3..PD1
            PB_ODR &= ~CC_10;    // Enable  common-cathode for 10s
            if (sound_alarm) ALARM_ON;
            mpx_nr = 1;
            break;
        case 1: // output 1s digit
            PC_ODR |= (led_1 & PORTC_LEDS);        // Update PC7..PC3
            PD_ODR |= ((led_1 << 1) & portd_leds); // Update PD3..PD1
            PB_ODR &= ~CC_1;         // Enable  common-cathode for 1s
            ALARM_OFF;
            mpx_nr = 2;
            break;
        case 2: // output 01s digit
            PC_ODR |= (led_01 & PORTC_LEDS);        // Update PC7..PC3
            PD_ODR |= ((led_01 << 1) & portd_leds); // Update PD3..PD1
            PD_ODR &= ~CC_01;        // Enable common-cathode for 0.1s
            if (sound_alarm) ALARM_ON;
            mpx_nr = 3;
            break;
        case 3: // outputs special digits
#if defined(FOUR_DIGITS_DISPLAY)
            if (menu_is_idle)
            {
                if (led_e & LED_POINT)     led_4 = LED_P; // P = 2nd temp. probe
                else if (led_e & LED_HEAT) led_4 = LED_H; // H = Heating mode
                else if (led_e & LED_COOL) led_4 = LED_C; // C = Cooling mode
            }
            if (led_e & LED_SET)
                 led_4 |=  LED_DECIMAL; // dp=1: Profile mode
            else led_4 &= ~LED_DECIMAL; // dp=0: Thermostat mode
            PC_ODR |= (led_4 & PORTC_LEDS);        // Update PC7..PC3
            PD_ODR |= ((led_4 << 1) & portd_leds); // Update PD3..PD1
#else
            PC_ODR |= (led_e & PORTC_LEDS);        // Update PC7..PC3
            PD_ODR |= ((led_e << 1) & portd_leds); // Update PD3..PD1
#endif
            PD_ODR &= ~CC_e;     // Enable common-cathode for extras
            ALARM_OFF;
        default: // FALL-THROUGH (less code-size)
            mpx_nr = 0;
            break;
            //mpx_nr = 0;
            //break;
    } // switch            
} // multiplexer()

/*-----------------------------------------------------------------------------
  Purpose  : This is the interrupt routine for the Timer 2 Overflow handler.
             It runs at 1 kHz and drives the scheduler and the multiplexer.
  Variables: -
  Returns  : -
  ---------------------------------------------------------------------------*/
#pragma vector = TIM2_OVR_UIF_vector
__interrupt void TIM2_UPD_OVF_IRQHandler(void)
{
    scheduler_isr();  // Run scheduler interrupt function
    if (!pwr_on)
    {   // Display OFF on dispay
	led_10     = LED_O;
	led_1      = led_01 = LED_F;
        led_e      = LED_OFF;
        pwr_on_tmr = 2000; // 2 seconds
    } // if
    else if (pwr_on_tmr > 0)
    {	// 7-segment display test for 2 seconds
        pwr_on_tmr--;
        led_10 = led_1 = led_01 = led_e = LED_ON;
    } // else if
    multiplexer();    // Run multiplexer for Display and Keys
    TIM2_SR1_UIF = 0; // Reset the interrupt otherwise it will fire again straight away.
} // TIM2_UPD_OVF_IRQHandler()

/*-----------------------------------------------------------------------------
  Purpose  : This routine initialises the system clock to run at 16 MHz.
             It uses the internal HSI oscillator.
  Variables: -
  Returns  : -
  ---------------------------------------------------------------------------*/
void initialise_system_clock(void)
{
    CLK_ICKR       = 0;           //  Reset the Internal Clock Register.
    CLK_ICKR_HSIEN = 1;           //  Enable the HSI.
    while (CLK_ICKR_HSIRDY == 0); //  Wait for the HSI to be ready for use.
    CLK_CKDIVR     = 0;           //  Ensure the clocks are running at full speed.
 
    // The datasheet lists that the max. ADC clock is equal to 6 MHz (4 MHz when on 3.3V).
    // Because fMASTER is now at 16 MHz, we need to set the ADC-prescaler to 4.
    ADC_CR1_SPSEL  = 0x02;        //  Set prescaler to 4, fADC = 4 MHz
    CLK_SWIMCCR    = 0;           //  Set SWIM to run at clock / 2.
    CLK_SWR        = 0xe1;        //  Use HSI as the clock source.
    CLK_SWCR       = 0;           //  Reset the clock switch control register.
    CLK_SWCR_SWEN  = 1;           //  Enable switching.
    while (CLK_SWCR_SWBSY != 0);  //  Pause while the clock switch is busy.
} // initialise_system_clock()

/*-----------------------------------------------------------------------------
  Purpose  : This routine initialises Timer 2 to generate a 1 kHz interrupt.
             16 MHz / (  16 *  1000) = 1000 Hz (1000 = 0x03E8)
  Variables: -
  Returns  : -
  ---------------------------------------------------------------------------*/
void setup_timer2(void)
{
    TIM2_PSCR    = 0x04;  //  Prescaler = 16
    TIM2_ARRH    = 0x03;  //  High byte of 1000
    TIM2_ARRL    = 0xE8;  //  Low  byte of 1000
    TIM2_IER_UIE = 1;     //  Enable the update interrupts
    TIM2_CR1_CEN = 1;     //  Finally enable the timer
} // setup_timer2()

/*-----------------------------------------------------------------------------
  Purpose  : This routine initialises all the GPIO pins of the STM8 uC.
             See stc1000p.h for a detailed description of all pin-functions.
  Variables: -
  Returns  : -
  ---------------------------------------------------------------------------*/
void setup_output_ports(void)
{
    PA_ODR      = 0x00; // Turn off all pins from Port A
    PA_DDR     |= (S3 | COOL | HEAT); // Set as output
    PA_CR1     |= (S3 | COOL | HEAT); // Set to Push-Pull
    PB_ODR      = (CC_10 | CC_1); // Turn off all pins from Port B (CC1 = CC2 = H)
    PB_DDR     |= (CC_10 | CC_1); // Set PB5..PB4 as output
    PB_CR1     |= (CC_10 | CC_1); // Set PB5..PB4 to Push-Pull
    PC_ODR      = 0x00; // Turn off all pins from Port C
    PC_DDR     |= PORTC_LEDS; // Set PC7..PC3 as outputs
    PC_CR1     |= PORTC_LEDS; // Set PC7..PC3 to Push-Pull
    PD_ODR      = (CC_01 | CC_e); // Turn off all pins from Port D (CC3 = CCe = H)
    PD_DDR     |= (0x40 | CC_01 | CC_e | portd_leds); // Set PD6..PD1 as outputs
    PD_CR1     |= (0x40 | CC_01 | CC_e | portd_leds); // Set PD6..PD1 to Push-Pull
} // setup_output_ports()

/*-----------------------------------------------------------------------------
  Purpose  : This task is called every 500 msec. and processes the NTC 
             temperature probes from NTC1 (PD3/AIN4) and NTC2 (PD2/AIN3)
  Variables: -
  Returns  : -
  ---------------------------------------------------------------------------*/
void adc_task(void)
{
  uint16_t temp;
  uint8_t  i;
  
  // Save registers that interferes with LED's and disable common-cathodes
  __disable_interrupt();      // Disable interrups while reading buttons
  save_display_state();       // Save current state of 7-segment displays
  PD_DDR &= ~AD_CHANNELS;     // Set PD3 (AIN4) and PD2 (AIN3) to inputs
  PD_CR1 &= ~AD_CHANNELS;     // Set to floating-inputs (required by ADC)  
  for (i = 0; i < 200; i++) ; // Disable to let input signal settle
  if (ad_ch)
  {  // Process NTC probe 1
     temp       = read_adc(AD_NTC1);
     ad_ntc1    = ((ad_ntc1 - (ad_ntc1 >> FILTER_SHIFT)) + temp);
     temp_ntc1  = ad_to_temp(ad_ntc1,&ad_err1);
     temp_ntc1 += eeprom_read_config(EEADR_MENU_ITEM(tc));
  } // if
#if !(defined(OVBSC))
  else
  {  // Process NTC probe 2
     temp       = read_adc(AD_NTC2);
     ad_ntc2    = ((ad_ntc2 - (ad_ntc2 >> FILTER_SHIFT)) + temp);
     temp_ntc2  = ad_to_temp(ad_ntc2,&ad_err2);
     temp_ntc2 += eeprom_read_config(EEADR_MENU_ITEM(tc2));
  } // else
#endif
  ad_ch = !ad_ch;

  // Since the ADC disables GPIO pins automatically, these need
  // to be set to GPIO output pins again.
  PD_DDR  |= AD_CHANNELS;  // Set PD3 (AIN4) and PD2 (AIN3) as outputs again
  PD_CR1  |= AD_CHANNELS;  // Set PD3 (AIN4) and PD2 (AIN3) to Push-Pull again
  restore_display_state(); // Restore state of 7-segment displays
  __enable_interrupt();    // Re-enable Interrupts
} // adc_task()

/*-----------------------------------------------------------------------------
  Purpose  : This task is called every 100 msec. and creates a slow PWM signal
             from pid_output: T = 12.5 seconds. This signal can be used to
             drive a Solid-State Relay (SSR).
  Variables: pid_out (global) is used
  Returns  : -
  ---------------------------------------------------------------------------*/
void pid_to_time(void)
{
    static uint8_t std_ptt = 1; // state [on, off]
    static uint8_t ltmr    = 0; // #times to set S3 to 0
    static uint8_t htmr    = 0; // #times to set S3 to 1
    uint8_t x;                  // temp. variable
     
    x = (uint8_t)(pid_out >> 3); // divide by 8 to give 1.25 * pid_out
    
    switch (std_ptt)
    {
        case 0: // OFF
            if (ts == 0) std_ptt = 2;
            else if (ltmr == 0)
            {   // End of low-time
                htmr = x; // htmr = 1.25 * pid_out
                if ((htmr > 0) && pwr_on) std_ptt = 1;
            } // if
            else ltmr--; // decrease timer
            S3_OFF;      // S3 output = 0
            led_e &= ~(LED_HEAT | LED_COOL); // disable both LEDs
            break;
        case 1: // ON
            if (ts == 0) std_ptt = 2;
            else if (htmr == 0)
            {   // End of high-time
                ltmr = 125 - x; // ltmr = 1.25 * (100 - pid_out)
                if ((ltmr > 0) || !pwr_on) std_ptt = 0;
            } // if
            else htmr--; // decrease timer
            S3_ON;       // S3 output = 1
            if (kc > 0) led_e |= LED_HEAT; // Heating loop active
            else        led_e |= LED_COOL; // Cooling loop active
            break;
        case 2: // DISABLED
            S3_OFF; // S3 output = 0;
            if (ts > 0) std_ptt = 1;
            break;
    } // switch
} // pid_to_time()

/*-----------------------------------------------------------------------------
  Purpose  : This task is called every 100 msec. and reads the buttons, runs
             the STD and updates the 7-segment display.
  Variables: -
  Returns  : -
  ---------------------------------------------------------------------------*/
void std_task(void)
{
    read_buttons(); // reads the buttons keys, result is stored in _buttons
    menu_fsm();     // Finite State Machine menu
    pid_to_time();  // Make Slow-PWM signal and send to S3 output-port
} // std_task()
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
int main(void)
{
    if (RST_SR_SWIMF) // Check for SWIM Debug Reset
         portd_leds = PORTD_LEDS_SWIM;
    else portd_leds = PORTD_LEDS;
    __disable_interrupt();
    initialise_system_clock(); // Set system-clock to 16 MHz
    setup_output_ports();      // Init. needed output-ports for LED and keys
    setup_timer2();            // Set Timer 2 to 1 kHz
#if !(defined(OVBSC))
    pwr_on = eeprom_read_config(EEADR_POWER_ON); // check pwr_on flag
#endif    
    // Initialise all tasks for the scheduler
    add_task(adc_task ,"ADC",  0,  500); // every 500 msec.
    add_task(std_task ,"STD", 50,  100); // every 100 msec.
    add_task(ctrl_task,"CTL",200, 1000); // every second
#if !(defined(OVBSC))
    add_task(prfl_task,"PRF",300,60000); // every minute / hour
#endif    
    __enable_interrupt();

    while (1)
    {   // background-processes
        dispatch_tasks();       // Run task-scheduler()
        //__wait_for_interrupt(); // do nothing
    } // while
} // main()

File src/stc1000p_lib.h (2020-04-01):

/*==================================================================
  File Name    : stc1000p_lib.h
  Author       : Mats Staffansson / Emile
  ------------------------------------------------------------------
  Purpose : This is the header-file for stc1000p_lib.c

            Most of these functions are directly copied from the
            Github library https://github.com/matsstaff/stc1000p.

            The original source is created by Mats Staffansson and
            adapted for the STM8S uC by Emile.
  ------------------------------------------------------------------
  STC1000+ is free software: you can redistribute it and/or modify
  it under the terms of the GNU General Public License as published by
  the Free Software Foundation, either version 3 of the License, or
  (at your option) any later version.
 
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
  You should have received a copy of the GNU General Public License
  along with STC1000+.  If not, see <http://www.gnu.org/licenses/>.
  ------------------------------------------------------------------
  $Log: $
  ==================================================================
*/ 
#ifndef STC1000P_LIB_H
#define STC1000P_LIB_H

#include <stdint.h>
#include <stdbool.h>
#include <intrinsics.h>
#include "stc1000p.h"
#include "eep.h"
#include "pid.h"

// Define limits for temperatures in Fahrenheit and Celsius
#define TEMP_MAX_F	  (2500)
#define TEMP_MIN_F	  (-400)
#define TEMP_CORR_MAX_F	  ( 100)
#define TEMP_CORR_MIN_F	  (-100)
#define TEMP_HYST_1_MAX_F ( 100)
#define TEMP_HYST_2_MAX_F ( 500)
#define SP_ALARM_MIN_F	  (-800)
#define SP_ALARM_MAX_F	  ( 800)

#define TEMP_MAX_C	  (1400)
#define TEMP_MIN_C	  (-400)
#define TEMP_CORR_MAX_C	  (  50)
#define TEMP_CORR_MIN_C	  ( -50)
#define TEMP_HYST_1_MAX_C (  50)
#define TEMP_HYST_2_MAX_C ( 250)
#define SP_ALARM_MIN_C	  (-400)
#define SP_ALARM_MAX_C	  ( 400)

// Values for temperature control STD
#define STD_OFF      (0)
#define STD_DLY_HEAT (1)
#define STD_DLY_COOL (2)
#define STD_HEATING  (3)
#define STD_COOLING  (4)

//---------------------------------------------------------------------------
// Basic defines for EEPROM config addresses
// One profile consists of several temp. time pairs and a final temperature
//
// Do NOT Forget to set:
// 1) proper #include in stc1000p.h: <iostm8s003f3.h> or <iostm8s103f3.h>
// 2) Project -> Options -> Target -> Device to STM8S003F3 or STM8S103F3
//---------------------------------------------------------------------------
#ifdef __IOSTM8S103F3_H__
#define NO_OF_PROFILES	 (6)
#define NO_OF_TT_PAIRS   (9)
#else
#define NO_OF_PROFILES	 (4)
#define NO_OF_TT_PAIRS   (5)
#endif
#define PROFILE_SIZE     (2*(NO_OF_TT_PAIRS)+1)
#define MENU_ITEM_NO	 NO_OF_PROFILES
#define THERMOSTAT_MODE  NO_OF_PROFILES

//-----------------------------------------------------------------------------
// Enum to specify the types of the parameters in the menu.
// Note that this list needs to be ordered by how they should be presented 
// on the display. The 'temperature types' should be first so that everything 
// less or equal to t_sp_alarm will be presented as a temperature.
// t_runmode and t_period are handled as special cases, everything else is 
// displayed as integers.
//-----------------------------------------------------------------------------
enum e_item_type 
{
    t_temperature = 0,
    t_tempdiff,
#if defined(OVBSC)
    t_percentage,
    t_period,
    t_apflags,
    t_pumpflags, 
#endif
    t_hyst_1,
    t_hyst_2,
    t_sp_alarm,
    t_step,
    t_delay,
    t_runmode,
    t_duration,
    t_boolean,
    t_bool_cf,
    t_parameter
}; // e_item_type

#if defined(OVBSC)
    #define MENU_TYPE_IS_TEMPERATURE(x) 	((x) <= t_tempdiff)
#else
    #define MENU_TYPE_IS_TEMPERATURE(x) 	((x) <= t_sp_alarm)
#endif
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

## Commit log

2016-11-08 PID controller update + Calculus pdf added
2016-11-12 User Manual updated with 5-pin terminal block
2016-11-16 Minor changes
    - Updates to User-Manual and readme.md file.
    - 7-segment now blinks all leds for a second at power-up and from
    power-off to power-on.
2016-12-02 Reduced code-size + STVP programming option added
    Reduced code-size by removing all bit-fields and unions. This saved over
    500 bytes of Flash memory.
    [stvp_stm8s003f3_4pr_5tt.stp, stvp_stm8s103f3_6pr_9tt.stp]
2016-12-16 PID switchable between heating- and cooling-loop
    Hc > 0 now selects heating-loop (forward acting PID), Hc < 0 selects
    cooling-loop (reverse acting PID). Relays are switched off when PID-mode
    is enabled.
    [stc1000p.c, stc1000p_lib.h]
2016-12-16 Bugfix: alarm did not work. Corrected
    [stc1000p.c, stc1000p.h]
2018-01-12 Bug-fix temperature_control() with Pb2==0
    If Pb2 is 0 and outside temperature (temp_ntc2) was > setpoint +
    hysteresis2, heating was not energised. This is corrected: if Pb2 is 0,
    temp_ntc2 is never used in temperature_control.
2018-04-07 Fixes #5 decimal dot now also for pid_output
    [stc1000p.c, stc1000p_lib.h]
2020-02-29 Refrigerator mode (Pb=2) with compressor fan control added: 1st test version
2020-03-01 Hysteresis always calculated, not only when relays are off
2020-03-06 Bugfix fan control hysteresis
2020-03-09 First version with OVBSC integration. Does still need a lot of work
    TODO: remove output and replace with pid setpoint for automated control. Use up and down key to manually control Pump and Heater.
    [stc1000p.c, stc1000p.h, stc1000p_lib.h]
2020-03-22 More bug-fixes for OVBSC mode
    TO-DO clearing of led_e leds.
    [stc1000p.c, stc1000p_lib.h]
2021-02-17 Updated for 4-digits CC 7-segment displays
    Use the define FOUR_DIGITS_DISPLAY for this. Works with frontpanel PCB v03.
    The former COMMON_ANODE code is removed, did not work well with switches.
    [stc1000p.c]
